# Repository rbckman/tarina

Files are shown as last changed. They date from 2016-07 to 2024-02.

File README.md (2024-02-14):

This project has been renamed to Gonzo Pi
==========================================

for the latest release go to [https://github.com/rbckman/gonzopi](https://github.com/rbckman/gonzopi)

Tarina Retake
=============
The Filmmaking Device

Let's introduce this thing with a thing it made, [a film on youtube](https://youtu.be/Yl2oAxMtDV0?si=lXOYTpkJi1YFuO2u) !

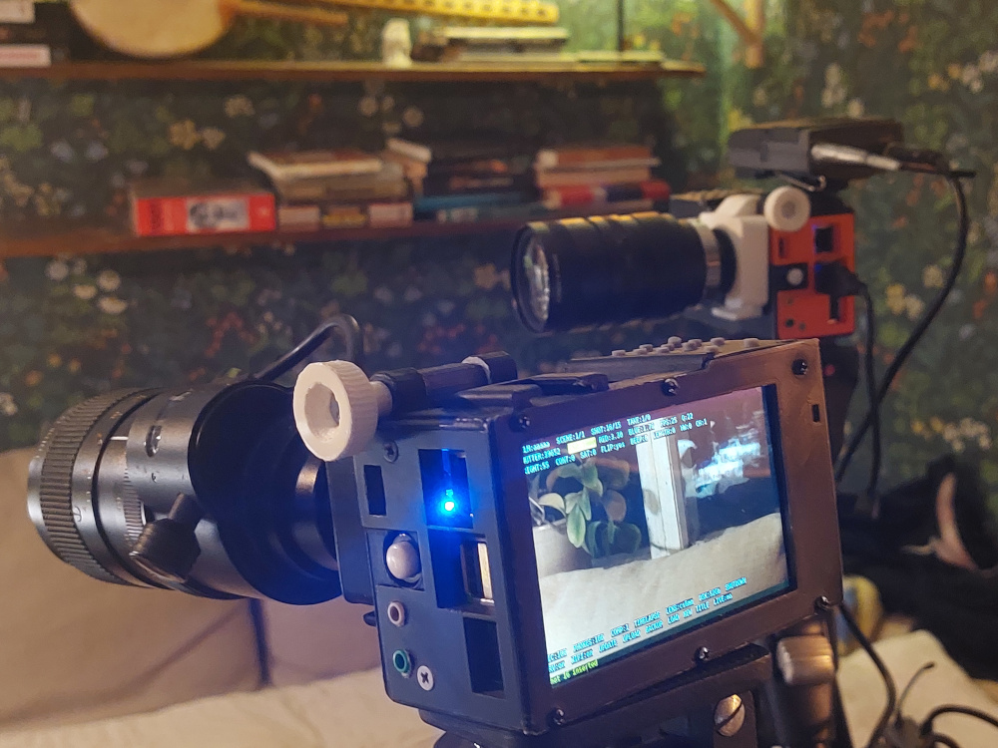
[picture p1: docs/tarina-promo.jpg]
Two buddies


Hollywood in your palms
--------------------------
Retake shots on the spot and see movie making magic in the filmmaking interface that runs Tarina Retake.
 
Software
--------
A video camera with *most of* the tools to make a film within the camera. That means alot of features. So far we have these key features running.
- glue the selected clips together and/or cutting them.
- making timelapses, voiceover, music track recording, slo-mo recording, fast-forward recording
- cut and copy and move clips around
- backup to usb harddrive or your own server
- upload or stream to youtube or your own server
- auto correction can easily be switched on or off for shutter, iso and colors so *operator* is in full control also for audio levels
- connect many Tarinas together for multicamera shooting
- stream a film a take or a scene through the network
- control the camera with silent physical buttons or a usb-wireless-keyboard or through https or ssh or ports, you choose.

It's all in there. But, where? in the filmmaking interface, that is Tarina Retake.

Hardware
--------
The parts have been chosen on the basis of features, quality, openness, availabilty and price. One of the key ideas of the project is to have a camera that could be upgraded or repaired by the fact that you easily just switch a component. The casis of the camera is 3d printable with a flipping gonzo style 180 shooting mode, please take a look [here to get the picture](https://github.com/rbckman/tarina/tree/master/3d)

### Buttons
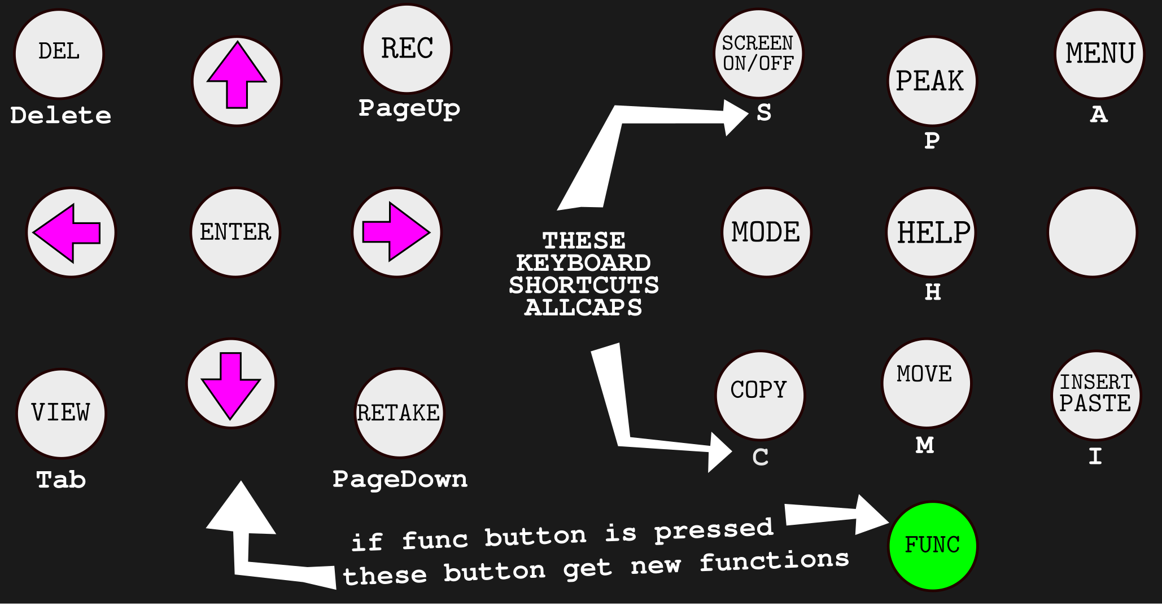
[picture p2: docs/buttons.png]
Buttons


Here's the main components: 

[Raspberry Pi 3 B](https://www.raspberrypi.org/products/raspberry-pi-3-model-b/)<br>
[Raspberry Pi High Quality Camera](https://www.raspberrypi.org/products/raspberry-pi-high-quality-camera/?resellerType=home) or <br>
[Pimoroni Hyperpixel 4 inch screen](https://learn.pimoroni.com/tutorial/sandyj/getting-started-with-hyperpixel-4)
[USB via vt1620a Sound card](https://www.aliexpress.com/item/Professional-External-USB-Sound-Card-Adapter-Virtual-7-1-Channel-3D-Audio-with-3-5mm-Headset/32588038556.html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)<br>
[3.7v 7800mAh li-ion Battery](https://www.aliexpress.com/item/3-7v-9000mAh-capacity-18650-Rechargeable-lithium-battery-pack-18650-jump-starter/32619902319.html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)<br>
[Type-C 5v 2A 3.7V Li-ion battery charger booster module](https://www.ebay.com/itm/Type-C-USB-5V-2A-3-7V-18650-Lithium-Li-ion-Battery-Charging-Board-Charger-Module/383717339632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)
[Buttons](http://www.ebay.com/itm/151723036469?_trksid=p2057872.m2749.l2649&ssPageName=STRK%3AMEBIDX%3AIT) connected to a [MCP23017-E/SP DIP-28 16 Bit I / O Expander I2C](http://www.ebay.com/sch/sis.html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)

Check [MANUAL](docs/tarina-manual.md) for complete part list & build instructions

[Ready to print 3d designs](https://github.com/rbckman/tarina/tree/master/3d)

Installing
----------
Download [Raspbian buster (not the latest!)](https://www.raspberrypi.org/downloads/raspbian/) and follow [install instructions | a simple install script should take care of it all!](https://www.raspberrypi.org/documentation/installation/installing-images/README.md).
[Ssh into](https://www.raspberrypi.org/documentation/remote-access/ssh/) Raspberry Pi and run:
```
sudo apt-get install git
```
Go to /home/pi/ folder
```
cd /home/pi
```
Git clone Tarina Retake and then run install script with sudo:
```
git clone https://github.com/rbckman/tarinaretake.git
cd tarinaretake
sudo ./install.sh
```
You'r ready to rumble:
```
python3 tarinaretake.py
```

Why
---
There are several reasons why.

- be able to repair if something breaks (this has been prooven as a very nice feature)
- be able to expand / build on it / make modifications
- be able to connect to it / program it to do things
- do a film on the fly without the need of another computer
- be able to watch your film directly on a screen once you're done filming
- learn about programming and your own crafts to really get down to the nitty-gritty. 

Connect
-------
Matrix [#tarina:matrix.tarina.org](https://riot.im/app/#/room/#tarina:matrix.tarina.org)

Mail rob(at)tarina.org

Standing on the shoulders of forward thinking, freedom loving generous people (powa to da people!)
--------------------------------------------------------------------------------------------------
This whole project has only been possible because of the people behind the free and open source movement. Couldn't possible list all of the projects on which shoulders this is standing for it would reach the moon. A big shout out to all of ya!! Yall awesome!

[Gnu](https://gnu.org), [Linux](https://github.com/torvalds/linux), [Debian](https://debian.org), [Raspberry Pi](https://raspberrypi.org), 
[Python programming language](https://python.org), Dave Jones's [Picamera python module](https://github.com/waveform80/picamera), rwb27 for lens shading correction! Check out the 3d printable microscope [Openflexure](https://github.com/rwb27/openflexure_microscope), [FFmpeg](https://ffmpeg.org/), [Libav-tools](https://libav.org/), [GPac library with MP4Box](https://gpac.wp.imt.fr/mp4box/), [Blender](http://blender.org), [aplay the awesome wav player/recorder with VU meter](http://alsa.opensrc.org/Aplay), [Popcornmix's Omxplayer](https://github.com/popcornmix/omxplayer), [Will Price's Python-omxplayer-wrapper](https://github.com/willprice/python-omxplayer-wrapper), [SoX - Sound eXchange](http://sox.sourceforge.net/), [The Dispmanx library](https://github.com/raspberrypi/userland/tree/master/host_applications/linux/apps/hello_pi), [Blessed](http://blessed.readthedocs.io/),  [web.py](http://webpy.org), [Tokland's youtube-upload](https://github.com/tokland/youtube-upload)

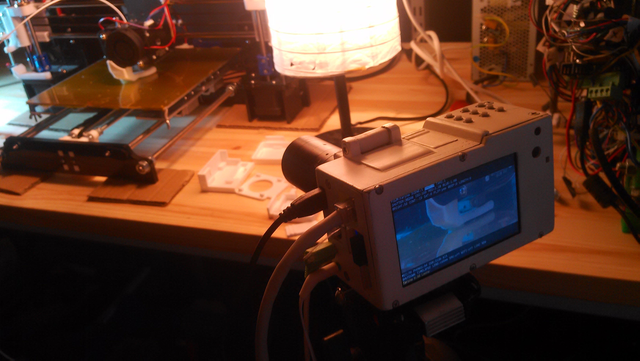
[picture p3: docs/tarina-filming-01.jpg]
Tarina and Leon


Some films made with Tarina
----------------------

### [Aakenustunturi Hiihtoretki 2023](https://youtu.be/VB7R2Eiw13k)

### [Mancherok](https://youtu.be/jmy0W6rA10Q)

### [Robins Trägård](https://youtu.be/IOZAHCIN6U0)

### [A new years medley](https://youtu.be/BYojmnD-1eU)

### [Landing Down Under](https://www.youtube.com/watch?v=Lbi9_f0KrKA)

### [Building Tarina](https://youtu.be/7dhCiDPssR4)

### [Mushroom Season](https://youtu.be/ggehzyUThZk)

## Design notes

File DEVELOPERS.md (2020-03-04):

DEVELOPERS
==========

If you want to join me in this journey to make the best open filmmaking camera please do not hesitate to contact me on features.

Teh best way to develop is using screen in terminal and starting tarina in one window then you'll get debug messages directly in that window.

THINGS
======

Notes to myself as I'm the only developer at teh moment.
-Rob

Quality / Usability
-------------------

Found a sweet spot between usability and quality (23), bitrate (5 mb/s)
This produces about 25 mb per minute. The convertion to mp4 format does not feel so slow anymore likewise the compiling of the film. This is good stuff.

Image sensors
-------------

There's plenty of image sensors for the Raspberry Pi to choose from, I want to support as many sensors I can. Currently though you need to change your sensor in tarina.py, search for 'ov5' and you'll find where to select. They all have different oscillators so the framerate varies pretty much. But when you get it right the sound will be in sync. Will make a tarina config file in home folder so when you start tarina interface for the first time it will ask you about your sensor.

Cancel renderer
---------------

This is a must feature, and I sort of know how to implement it.

Viewfinder for 3.5 inch screen
------------------------------

There's no such thing to buy so I had to make a viewfinder myself, took a while before I found the right convex lens but I have it now. It works with magnet snap on. Really, really usefull! will write it in the manual as a addon thing...

How to update alsa-tools arecord
=================================

The vumeter comes directly from alsa-tools arecord, it's just modified so it writes the vumeter directly to /dev/shm/vumeter. If you need to update alsa-tools here's how:

You need to be able to build alsa-utils from source
enable dev-src in /etc/apt/sources.list

```
apt source alsa-utils
cd alsa-utils*
sudo apt update
sudo apt install libncurses5-dev
sudo apt install libasound2-dev
./configure
make
cd aplay
make
make arecord
```

Ecasound update
===============

### Python example

```
from pyeca import *
e = ECA_CONTROL_INTERFACE()
e.command("cs-add chainsetup")
e.command("c-add 1st_chain")
e.command("ai-add plughw,0,0 ")
e.command("ao-add /dev/dsp")
e.command("cop-add -efl:100")
e.command("cop-select 1")
e.command("copp-select 1")
e.command("cs-connect")
e.command("start")
```

### Ecasound config file

```
# ecasound chainsetup file

# general 
-B:rtlowlatency -n:"write_chain" -X -z:noxruns -z:nopsr -z:mixmode,sum

# audio inputs 
-a:1chain,2chain -f:s16_le,2,44100 -i:alsahw,3,0,0

# audio outputs 
-a:1chain -f:s16_le,2,44100 -o:alsahw,3,0,0
-a:2chain -f:s16_le,2,44100 -o:test.wav,
```

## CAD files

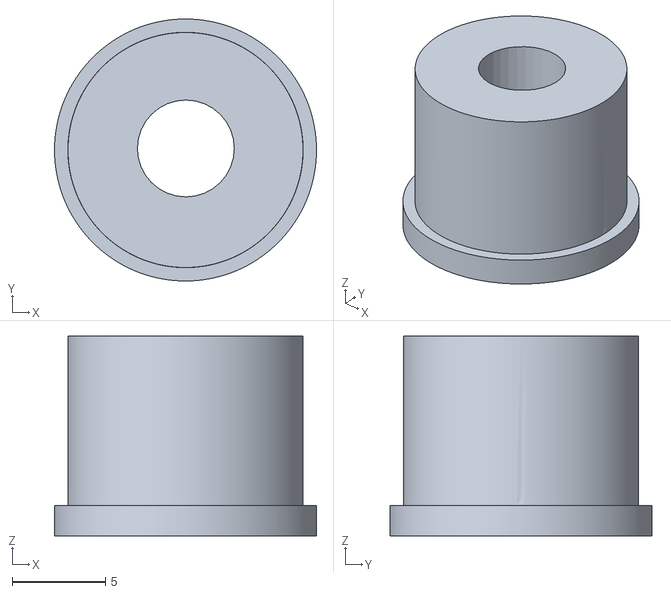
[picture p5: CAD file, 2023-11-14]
3d/tarina-picamera-clipgrip.stl
14.1 x 14.1 x 10.7

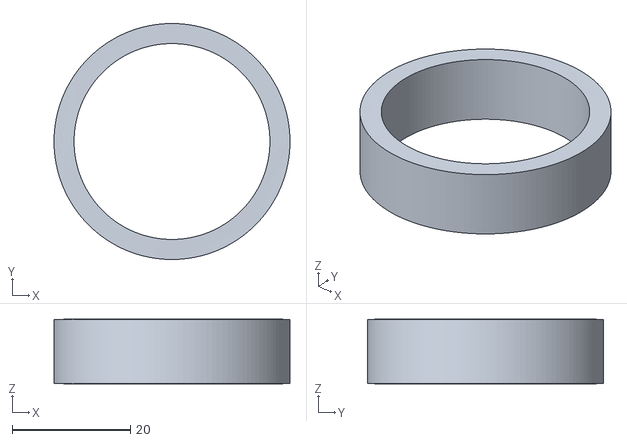
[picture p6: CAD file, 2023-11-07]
3d/tarinaloop.stl
40.0 x 40.0 x 11.0

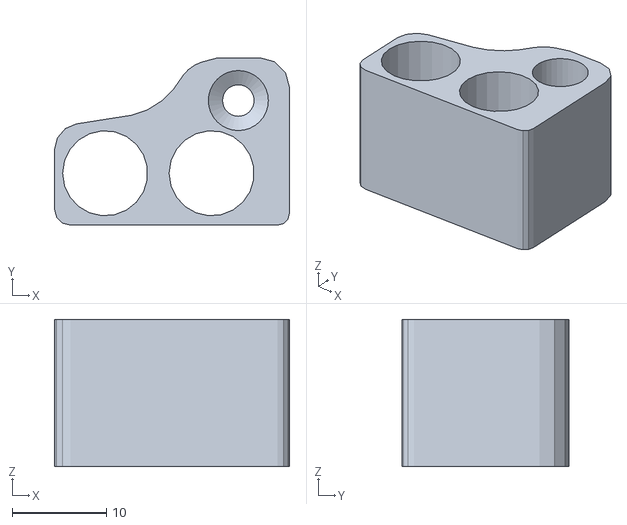
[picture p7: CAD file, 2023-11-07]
3d/miniplug-bend-stopper.stl
24.9 x 17.8 x 15.6

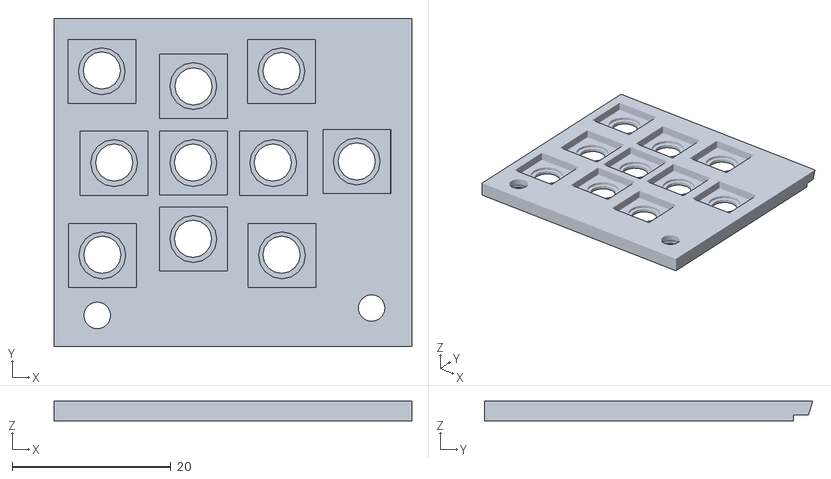
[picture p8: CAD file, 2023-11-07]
3d/tarina-button-plate-upper.stl
45.1 x 41.4 x 2.51

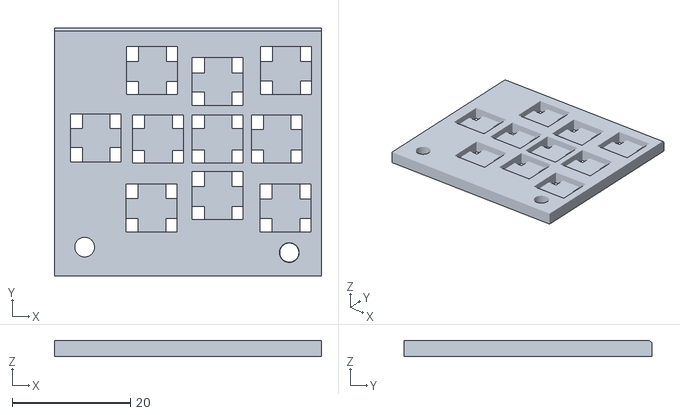
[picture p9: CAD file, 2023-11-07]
3d/tarina-button-plate-bottom.stl
45.1 x 41.9 x 2.71

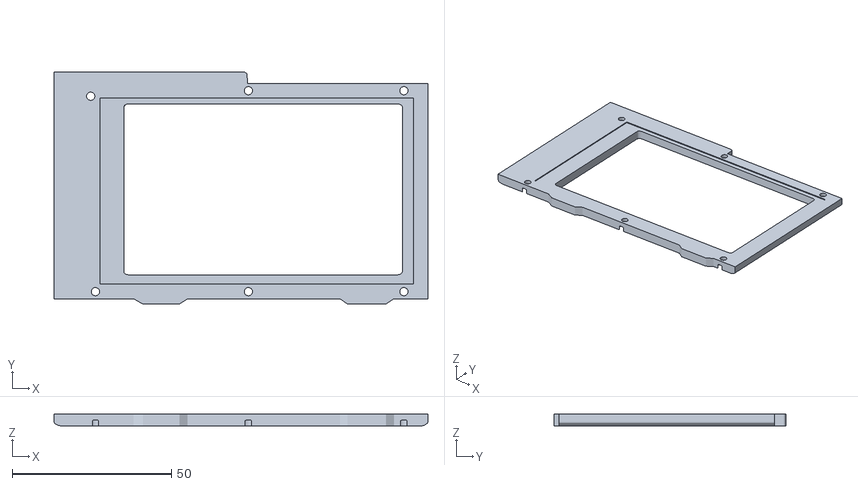
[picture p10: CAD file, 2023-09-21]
3d/tarina-screen-lid-hyperpixel.stl
117.4 x 72.8 x 3.68

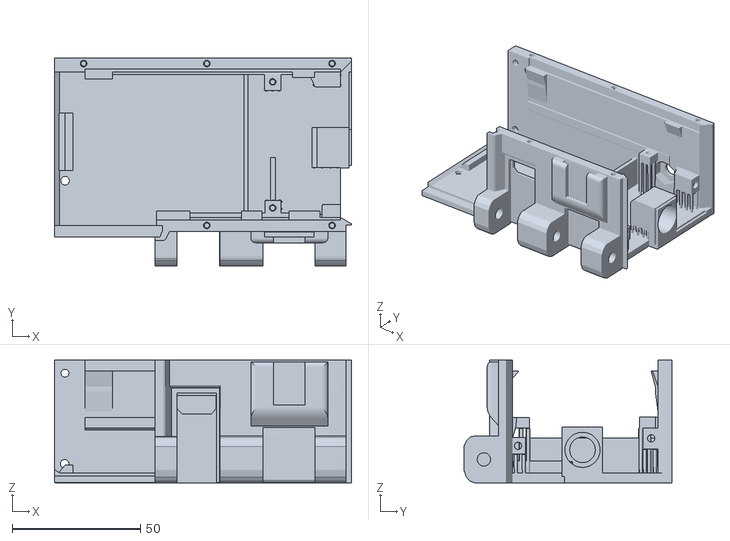
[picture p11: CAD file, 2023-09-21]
3d/tarina-body.stl
115.7 x 81.2 x 47.9

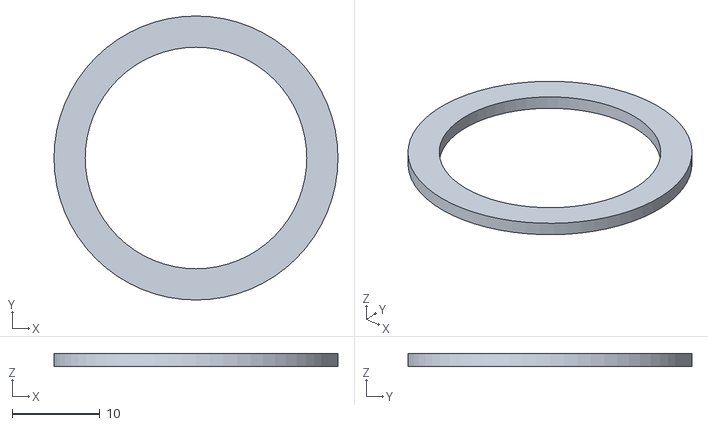
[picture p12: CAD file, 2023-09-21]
3d/cs-extension-tube.stl
32.4 x 32.4 x 1.50

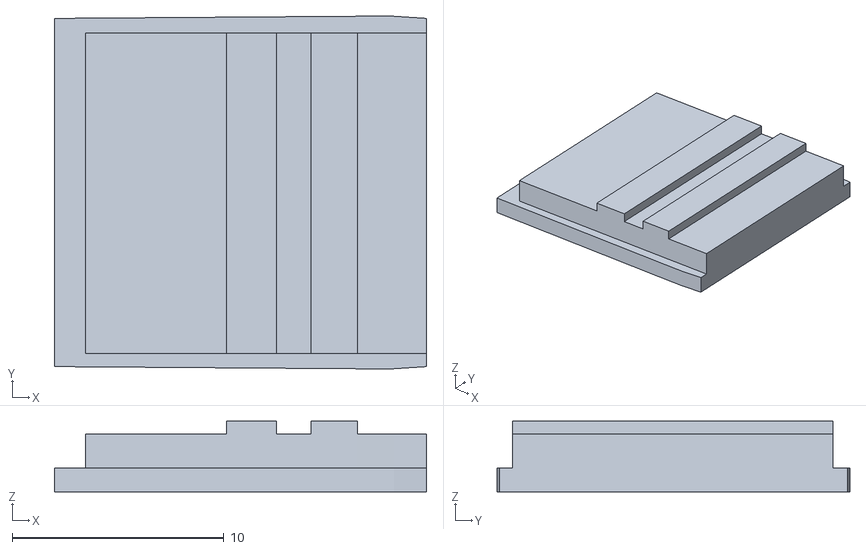
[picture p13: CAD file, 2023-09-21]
3d/tarina-hdmi-cap.stl
17.6 x 16.6 x 3.35

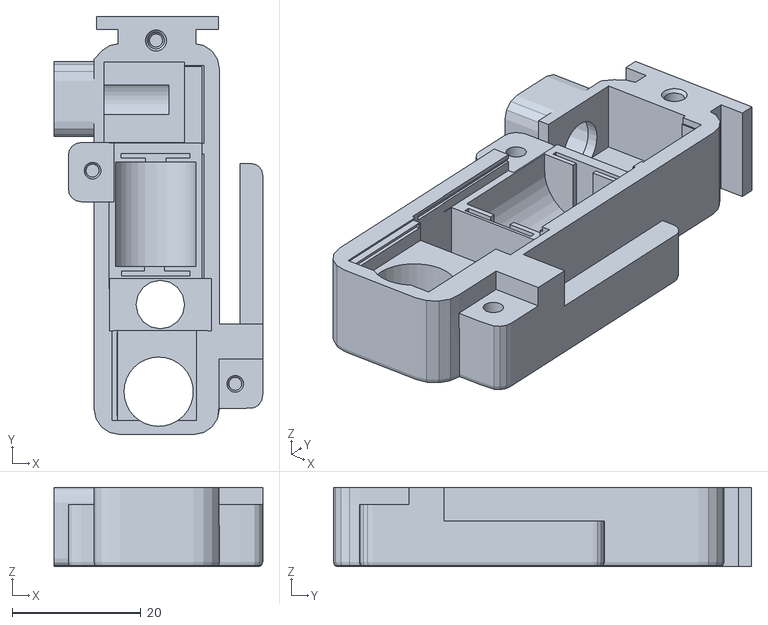
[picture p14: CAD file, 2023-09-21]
3d/tarina-mic-body.stl
32.3 x 64.8 x 12.3

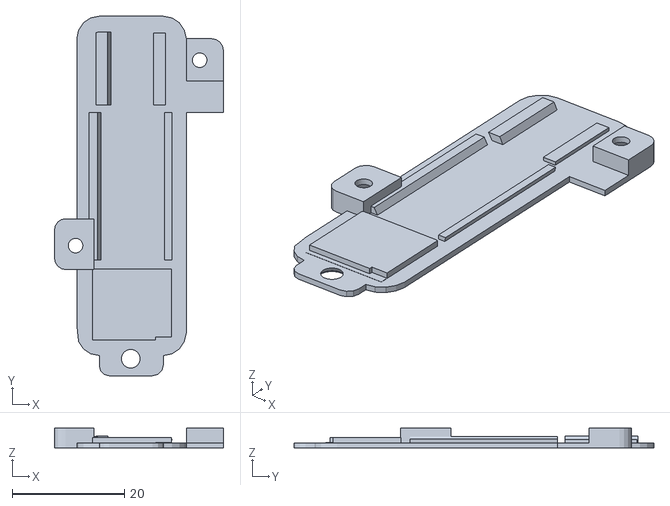
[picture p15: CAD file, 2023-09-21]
3d/tarina-mic-lid.stl
30.1 x 64.1 x 3.55

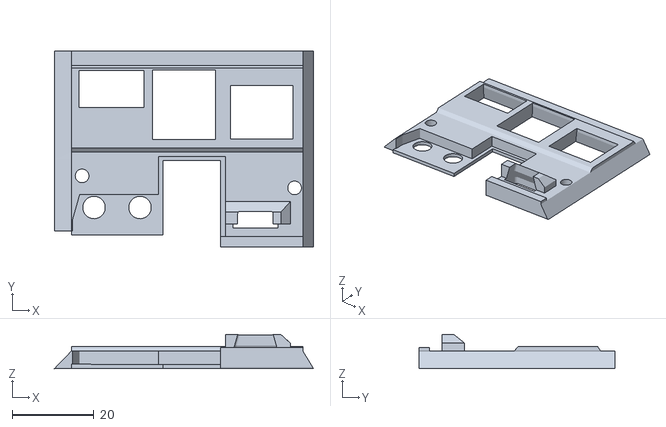
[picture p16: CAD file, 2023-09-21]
3d/tarina-left-side.stl
63.2 x 47.9 x 8.32

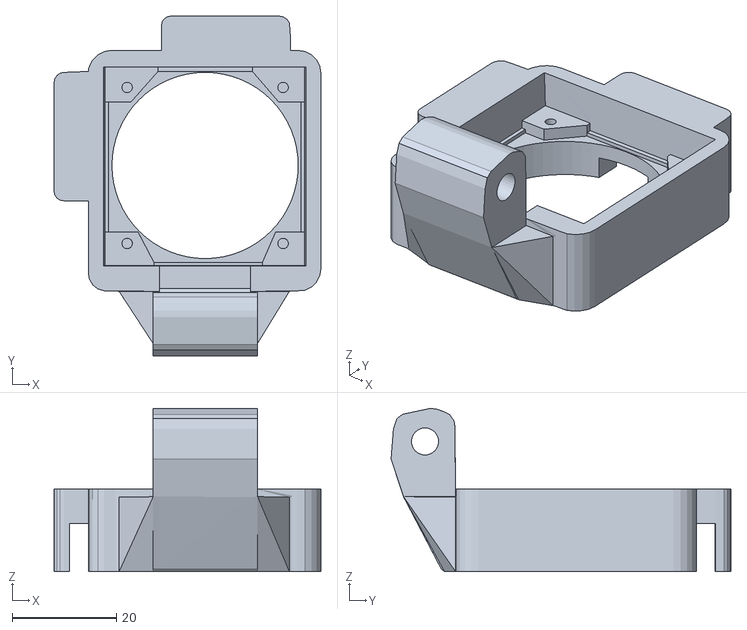
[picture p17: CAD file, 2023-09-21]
3d/tarina-picamera-hq-body.stl
51.3 x 65.3 x 31.4

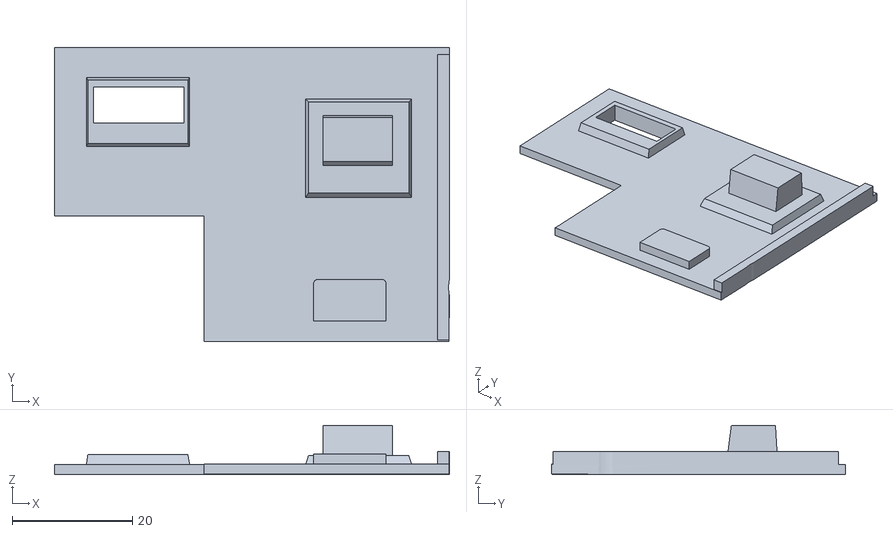
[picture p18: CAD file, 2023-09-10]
3d/tarina-left-side-cap.stl
65.7 x 48.9 x 8.18

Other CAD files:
3d/tarina-right-side.stl
3d/tarina-screen-lid-ugeek.stl
3d/tarina-picamera-hq-body-lid.stl
3d/viewfinder-clip-bridge3.stl
3d/button-symbols.stl
3d/tarina-modifyer-body-logo.stl
3d/tarina-modifyer-button-icons.stl
3d/tarina-picamera-body-lid.stl
3d/tarina-picamera-body.stl
3d/tarina-picamera-bridge.stl
3d/tarina-picamera-screwhandle.stl
3d/tarina-plate.stl
3d/tarina-screen-lid.stl
3d/tarina-viewfinder-eyepiece.stl
3d/tarina-viewfinder-hyperpixel.stl
3d/tarina-viewfinder.blend
3d/tarina-viewfinder.stl
3d/viewfinder-clip-bridge.stl
3d/viewfinder-clip-bridge2.stl

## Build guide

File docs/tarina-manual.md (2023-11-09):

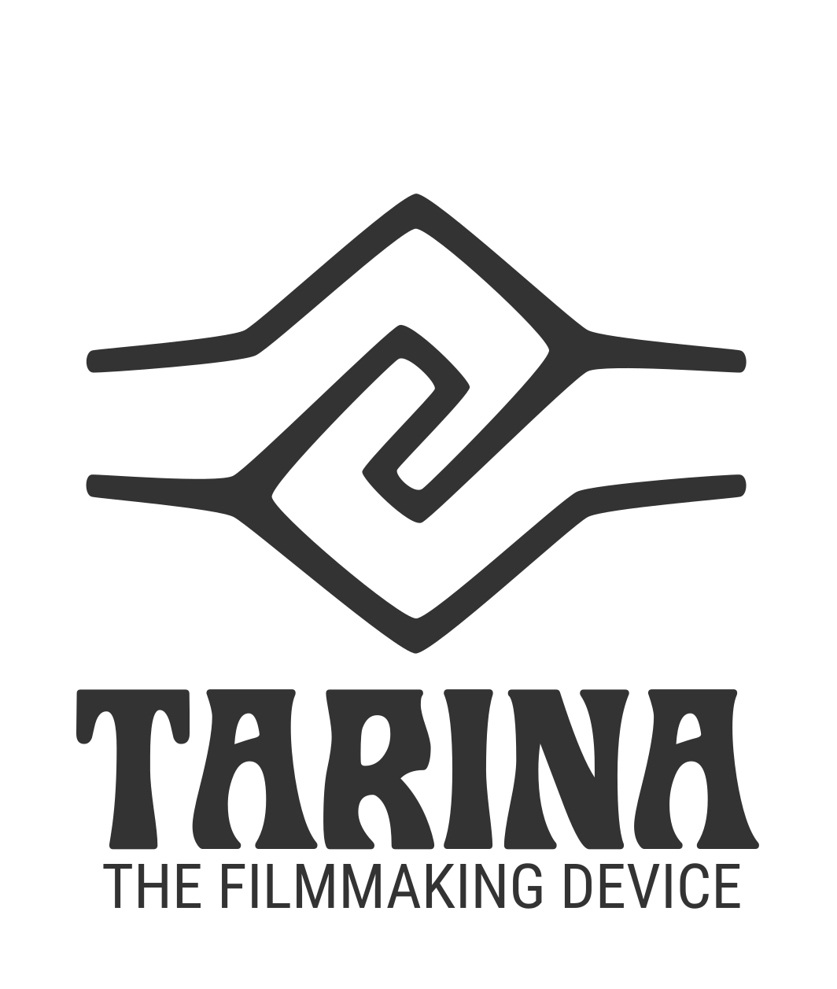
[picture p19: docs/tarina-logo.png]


<br>

MANUAL
======

Filming with Tarina

Contents
--------
### The interface
1. [Introduction](#introduction)
2. [Keys](#keys)
3. [Menus](#menus)
4. [Faq](#faq)

### [Building, repairing & modding]
1. [Get the parts](#get-the-parts)
2. [3d printing](#3d-printing)
3. [Post processing](#post-processing)
4. [Wiring](#wiring)
5. [Putting it together](#putting-it-together)
6. [Installing software](#installing-software)
7. [Tested lenses](#tested-lenses)

Introduction
============
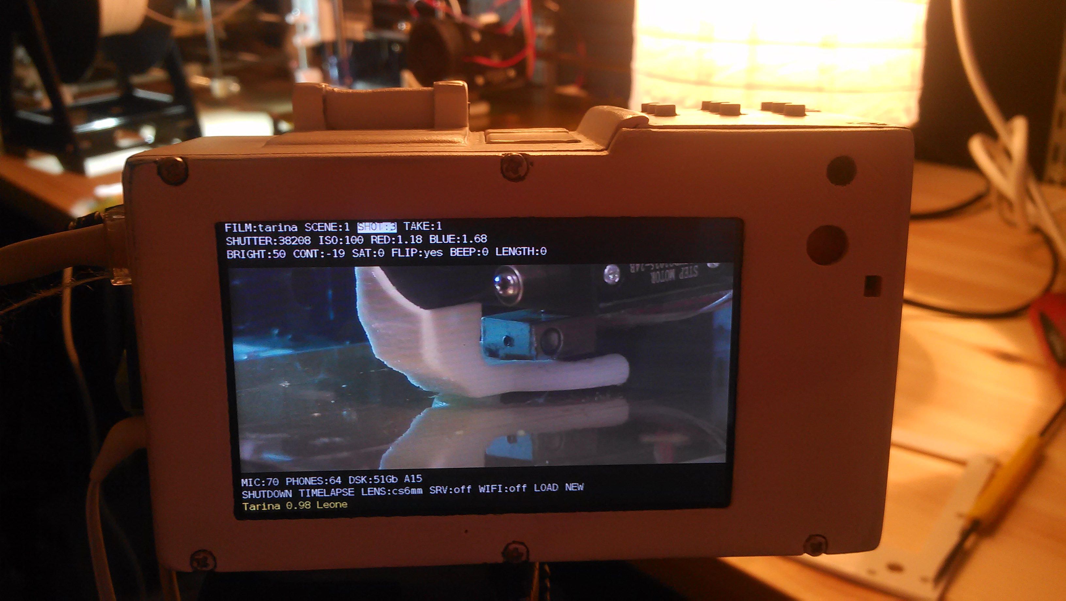
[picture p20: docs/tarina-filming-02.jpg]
Tarina UI


The interface presents all the essential tools in film making under one menu that is present and accessible all the time. You can control it with a keyboard or with the physical buttons; Enter, Up, Down, Left, Right, Record, Retake, View and Remove.

Retake function
---------------

Always after recording a take you'll be presented with the last frame of that take. Now, if you are happy with it, press record again and you'll move to the next shot in your movie, oterwise press retake and you'll be filming a new take of that shot. At the time of writing the last take is always chosen into your movie film.

Hint! pressing record while browsing existing takes, shots and scenes will take you to the last shot in that scene. Pressing retake will do just that, a retake. Makes perfectly sense, right? Fiddle around with it, you'll totally get it.

Keys
====

### Buttons
Buttons

### Keyboard
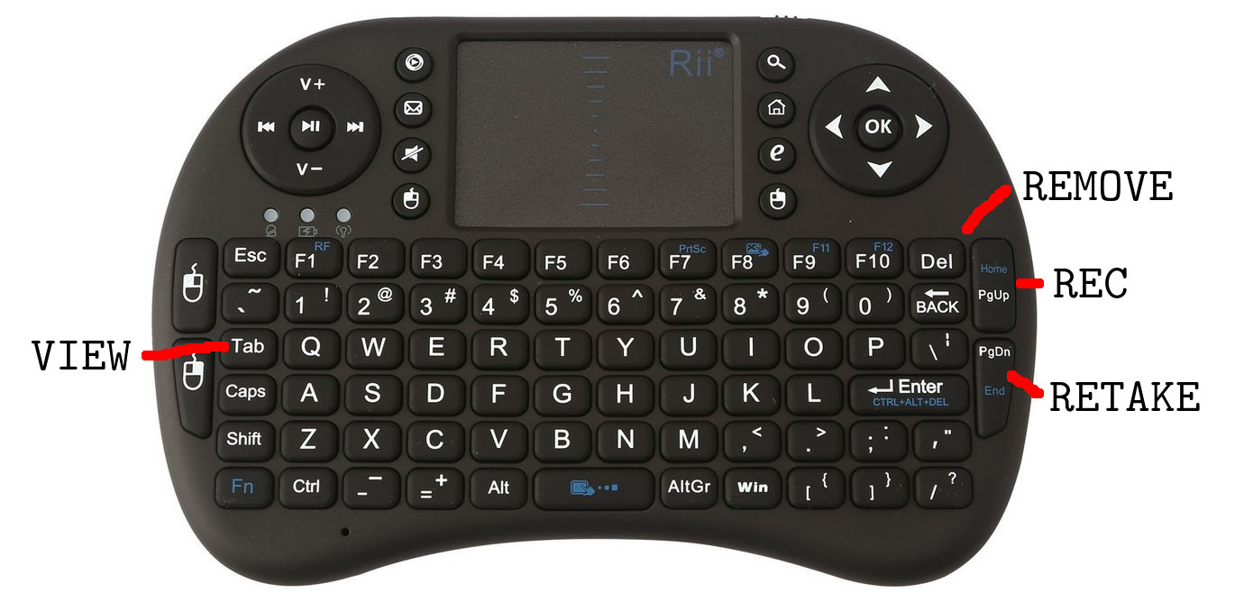
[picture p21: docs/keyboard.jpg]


With keys up and down you change a specific setting, for example shutter speed. With keys left and right you change what settings to change. With view, you can view the last shot or if you have a specific scene highlighted the camera would automatically glue all shots together and play that scene for you, same goes for film. With remove you can remove a specific take, shot, scene or film. With the retake button you retake a bad take, this is how the camera keeps track of your good takes. The last take is always the chosen one.

Special keys on the keyboard (CAPITAL):

C = Copy scene/shot

M = Cut (as in cut and paste) scene/shot

I = Insert empty or copied scene/shot

space / pgup = Rec / Stop

pgdwn / backspace = Retake

tab = view

Menus
=====
A short explanation of all the settings and why they are where they are.

### Film, scene, shot and take
This you don't see on other cameras because they don't care about what you're filming, however this camera does and it wants to know where you are in your filmmaking process and help put it together. Of course, this means that ***you*** have to know where you are in your filmmaking process. The idea of the workflow is: film only the essentials, check your montage on the spot and do a retake if you need to fix something rather than filming a bunch of things and fixing it later on. This will save ***you*** alot of time.

### Dubbing
If you press enter while you've highlighted the film name or a scene you'll be entering dub settings menu. (ADD:d:1.0/o:1.0) this indicates the volume of the (d)ub to the previous (o)riginal mix. So, for example if you want the dub volume to be 50% of the previous audio, the settings would look like this (ADD:d:0.5/o:1.0). A good all-around background music volume level is only 10% so it would look like this (ADD:d:0.1/o:1.0). The other setting is fade in and out in seconds (in: 0.5) (out: 1.0) whould be half a second in and a second out. Now if you press enter while the ADD is highlighted you'll be dubbing. You can change the settings later if you come back to the menu.

### Shutter, iso, red, blue
Shutter and iso are well know basic camera concepts. With red and blue you control the colors. If you press enter while on any of these then it will go into auto mode and if you press it again it will go back to manual mode with the current auto settings. I'm using this feature to quickly find a reasonable good value before I'm locking and tuning the settings manually to my likings. Cuz you always will know better than the robots!

### Bright, cont, sat
Color grade on the go with brightness, contrast and saturation. You will probably have to play with theses to figure out what you want. Remember that as you're making your film ready while you're shooting it take by take, there's no color grading later on so you'll have to settle on your color grade before you film. To get that good old spaghetti western look go with the contrast at -19.

### Flip, beep, lenght
If you go gonzo, flippin it is the way to go! beep is a countdown timer from the moment you press rec or retake to when it actually starts filming. Lenght let's you put in the lenght of your take before you actually start filming. Both of these are very useful if you film action alone and can't reach for the buttons. 

### Mic, phones, comp
Control teh level of your mic and headphones. Comp is a basic compressor so your message comes across and we hear ya! it's quite harsh at the moment but I like it when it goes craking up abit like in the good old 70s cinema.

### Timelapse
Do a timelapse when you need to tell about time. There's an under menu here where you can choose the intervall of the takes, now this isn't really a traditional timelapse, it will instead do a 0.2 sec video at each intervall or it can be set to your likings but 0.2 is good for a traditional timelapse effect. At the bottom of the screen is a calculation of how long the clip will be if you do the timelapse for an hour. I'd say don't over do it! a 10 - 20 sec clip is already quite a stretch but its up to you, you're the movie film director.

### Lens
A future implementation of lens shade correction will come where you get to do your own lens corrections to get those colors right on the spot!

### Dsk, shutdown, srv, wifi
Disk space, showing you how much of space left on your sd card. Shutdown, when your really done! it's good to do this before cutting the power or otherwise there's a small chance of sd card corruption. Srv is a network server, if your connected to a network and put this on you should be able to go to any browser on any device and watch your movie films (that is if you've rendered them first), just go to http://tarina.local or it might be that you have to know the ip address of your tarina (you'll find it when you've connected it. Press enter on wifi. There it is on the bottom of the screen, looks like this 192.168.1.105). If you press enter on wifi you will be transported to a glorious program called Wicd curses, here you really need to have a keyboard to set up your connections. Hints are down on the screen what buttons to press. To get back into Tarina press "q".

### Update and upload
Update the camera to the most exclusive version, this is still pretty much a-work-in-progress and as a warnign expect some bugs! don't worry I'll be improving things but it takes time. Upload your film to the web, there is a youtube uploader mod you can install but you'll have to do some configs to make it work for you. Details coming soon. Reach out to the matrix room if you're in a hurry..

to get the youtube api secrets `wget https://tarina.org/yt/.client_secrets.json`

### Backup
It's good to always backup your stuff! Plug in your usb drive and just press enter and sit back and relax as the wonderful work of computer copying does the magic. While you're at it open a beer cuz it can take quite a while if you got much stuff on there. Now, this should be working on almost all hard drives but there are some that still use a very old file system called fat, and its as lazy as its given name and doesnt store critical information we would want, because we want the copying to only copy our new takes or retakes. So please use new drives like ntfs systems or ext or whatever they all are called. You'll find all your takes even the shitty ones on your harddrive in a directory called /tarinafilms/. One more thing, there are some drives that are very power hungry and doesnt come with it's own power source, now these drives are very bad for this particular use because the Tarina has limited amounts of power for usb use, so to be sure it's gonna work, use powered hard drives that has got a power cord.

### Load and new
You can have many on going films, load em up or start as many films as you like.

------------------------------

Building, repairing and modding
===============================

Get the parts
--------------

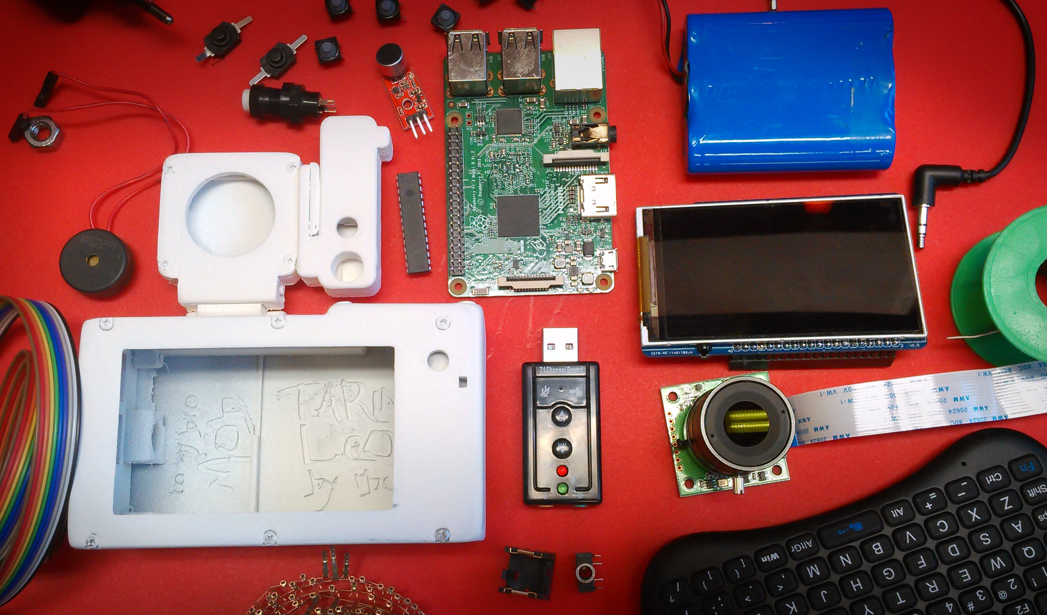
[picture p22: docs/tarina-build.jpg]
Tarina parts layed out


Here is a list of parts that will work, there are other parts that probably will work but requires some hacking.

Raspberry pi 3 B
----------------
Price ~30 eur

The heart of Tarina. Why Raspberry pi you ask? There are several reasons:

* Huge support.
* The great Debian based os Raspbian (beeing a debian nerd myself).
* Low price.
* Picamera.

The 3B+ is too powerhungry for the Powerbooster 1000C thats why I went with 3B

**Links**
[Raspberry pi site](https://raspberrypi.org)
**Buy**
[Aliexpress](https://www.aliexpress.com/store/product/Raspberry-Pi-3-Model-B-Raspberry-Pi-Raspberry-Pi3-B-Pi-3-Pi-3B-With-WiFi/3242037_32900816535.html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,searchweb201602_5_10065_10068_5016020_5015416_10059_10696_100031_5015320_10084_10083_10103_451_10618_452_5016116_10304_10307_10820_10821_10302,searchweb201603_55,ppcSwitch_2&algo_expid=0a48bb10-5985-49ff-be76-433eb1f8685b-15&algo_pvid=0a48bb10-5985-49ff-be76-433eb1f8685b&priceBeautifyAB=0)

64 Gb Samsung Evo+ Micro SD
---------------------
Price ~10 eur

This is a good performance card.

[Aliexpress](https://www.aliexpress.com/item/32676225311.html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,searchweb201602_7,searchweb201603_55)

Raspberry Pi High Quality Camera (recommended)
----------------------------------------------
Price ~60 eur

This is the recommended camera module for Tarina, 12.3 megapixel Sony IMX477 sensor, 7.9mm diagonal image size, and back-illuminated sensor architecture, with adjustable back focus and support for C- and CS-mount lenses.

**Links**
**Buy**
[Raspberry pi](https://www.raspberrypi.org/products/raspberry-pi-high-quality-camera/?resellerType=home)

Arducam 5 MP OV5647 camera module with CS lens
----------------------------------------------
Price ~30 eur

This module and lens gives good hd video quality with the ability to manually focus and replace lenses. See tested lenses down below.

**Links**
[Arducam](http://arducam.com/)
**Buy**
[ebay](https://www.ebay.com/itm/OV5647-Camera-Board-w-CS-mount-Lens-for-Raspberry-Pi-3-B-B-2-Model-B-/281212355128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)

Pimoroni Hyperpixel 4 inch screen
-----------------------------
Price ~35 eur

Bright 4 inch responsible screen. Beware when installing the screen, it's quite britle!

**Links**
[Pimoroni](https://learn.pimoroni.com/tutorial/sandyj/getting-started-with-hyperpixel-4)
**Buy**
[Pimoroni](https://shop.pimoroni.com/products/hyperpixel-4)
[Farnell](https://fi.farnell.com/pimoroni/pim370/hyperpixel-board-raspberry-pi/dp/3401805)

Ugeek 3.5 inch 800x480 TFT screen
---------------------------------
Price ~35 eur

Best 3.5 inch screen that I could find. Features worth mentioning:

* 800x480 pixels
* Very responsible 11 ms.
* High contrast.
* Sunlight readable. (even though it is readable in full power mode, it boots into medium power and to change it yo to push a physical button which isnt really dooable cuz of tha casing. you cant easily change the settings, I am abandoning this screen due to this)
* I2C Master.

This is not a touchscreen but I dont think touchscreens are good for cameras anyway. 

**Links**
[Raspberrypiwiki](http://www.raspberrypiwiki.com/index.php/3.5_inch_TFT_800x480@60fps)
**Buy**
[Aliexpress](https://www.aliexpress.com/store/product/U-Geek-Raspberry-Pi-3-5-inch-800-480-TFT-Screen-HD-HighSpeed-LCD-Module-3/1954241_32672157641.html)

USB via vt1620a sound card
--------------------------
Price ~1 eur

Really cheap usb soundcard. It has been working suprisingly well. Have not tested other cards yet.

**Buy**
[Aliexpress](https://www.aliexpress.com/item/Professional-External-USB-Sound-Card-Adapter-Virtual-7-1-Channel-3D-Audio-with-3-5mm-Headset/32588038556.html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)

3.7v 7800mAh li-ion Battery
---------------------------
Price ~17 eur

I have tried several batteries, the adafruit 6800mAh is also fine.

**Buy**
[Aliexpress](https://www.aliexpress.com/item/free-shipping-3-7v-7800mah-18650-li-ion-rechargeable-battery-pack-18650-3P-lithium-ion-battery/32823635264.html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)

Or you can buy 3 pcs of 3.7V 18650 Lithium cells and protect them with an Lithium Battery Protection Board Overcharge Over-discharge.

[Aliexpress](https://www.aliexpress.com/item/32826851071.html?spm=a2g0s.9042311.0.0.27424c4dUBojcv)

Here's a pack with 40 pcs of 2600mAh 3.7V 18650 cells.

[Aliexpress](https://www.aliexpress.com/item/32795814865.html?spm=a2g0s.9042311.0.0.27424c4dUBojcv)

Type-C 5v 2A 3.7V Li-ion battery charger booster module
-------------------------------------------------------
Price ~2€

Enough juice in this booster charger to run teh pi 3b without dropping voltage.

**Buy**
[Ebay](https://www.ebay.com/itm/Type-C-USB-5V-2A-3-7V-18650-Lithium-Li-ion-Battery-Charging-Board-Charger-Module/383717339632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)

Adafruit Powerboost 1000C
-------------------------
Price ~23 eur

Seems to be dropping voltage every now and then resulting in dropped frames. Check the Type-C power booster.

**Links**
[Adafruit](https://www.adafruit.com/product/2465)
**Buy**
[Ebay](https://www.ebay.com/itm/Adafruit-PowerBoost-1000-Charger-Rechargeable-5V-Lipo-USB-Boost-1A-1000C-A/282083284436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)
[Aliexpress](https://www.aliexpress.com/item/32881790567.html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,searchweb201602_7,searchweb201603_55)

8x8x5MM DIP-4 Silicone Switch Mute Silent button
------------------------------------------------
Price ~2 eur/20 pcs

You can only buy a pack of 20 pcs but these buttons are good and silent! Not necessary if you want to control with keyboard like Rii mini 8+

**Buy**
[Ebay](http://www.ebay.com/itm/151723036469?_trksid=p2057872.m2749.l2649&ssPageName=STRK%3AMEBIDX%3AIT)
[Aliexpress](https://www.aliexpress.com/item/32777086031.html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,searchweb201602_7,searchweb201603_55)

MCP23017-E/SP DIP-28 16 bit I / O expander I2C
-----------------------------------------------
Price ~1 eur

This will be connected to the screen I2C port. This is not necessary if you intend to control the camera with a keyboard like the Rii mini i8+

**Buy**
[Aliexpress](https://www.aliexpress.com/item/10PCS-MCP23017-E-SP-DIP-28-MCP23017-16-Bit-I-O-Expander-with-I2C-Interface-IC/32665631086.html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)

2x8cm double side copper prototype pcb
--------------------------------------
Price ~0.20 eur/pcs

PCB board to solder all connections on the MCP23017-E/SP

**Buy**
[Aliexpress](https://www.aliexpress.com/item/5pcs-2x8cm-double-Side-Copper-prototype-pcb-2-8-panel-Universal-Board-for-Arduino-Free-Shipping/32820588012.html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)

Piezo electronic buzzer
-----------------------
Price ~1 eur

Very useful for timing shots!

**Buy**
[Aliexpress](https://www.aliexpress.com/store/product/New-Arrival-Durable-3-24V-Piezo-Electronic-Buzzer-Alarm-95DB-Continuous-Sound-Beeper-For-Arduino-Car/1959068_32666789405.htm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,searchweb201602_3_10065_10068_10059_5015413_5015313_10696_100031_10084_10083_5016113_10103_451_10618_452_10304_10307_10820_10821_10302_5016013,searchweb201603_45,ppcSwitch_4_ppcChannel&algo_expid=c84318cd-b50e-4370-9cad-6ae9bc7963ae-0&algo_pvid=c84318cd-b50e-4370-9cad-6ae9bc7963ae&priceBeautifyAB=0)

Latching push button switch mini
---------------------------------
Price ~1 eur/10 pcs

This serves as the microphone and screen on/off button

**Buy**
[Aliexpress](https://www.aliexpress.com/item/10Pcs-Set-1A-30V-DC-250V-Black-Latching-On-Off-Mini-Torch-Push-Button-Switch-G08/32756874522.html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)

Latching push button switch 10mm
--------------------------------
Price ~5 eur/24 pcs

I use this as the powerbutton. I have tried different versions of safe shutdown buttons for the Raspberry pi but they have not worked as I wanted (they draw power even when Pi is powered off, this is not good). I have solved the problem with a menu button to safely shut down the camera. 

**Buy**
[Aliexpress](https://www.aliexpress.com/item/24pcs-latching-push-button-switch-10mm-fixed-pushbutton-switch-latching-maintained-push-buttons/32770346793.html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)

Nut 1/4 -20 UNC 304 A2 
-----------------------
Price ~2 eur/10 pcs

This is the standard camera stand nuts. If you never use a stand then you dont need this.

**Buy**
[Ebay](https://www.ebay.com/itm/1-4-20-UNC-304-A2-Stainless-Steel-Hex-Full-Nuts-Qty-10PCS-/222134363896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)<br>

MAX9812 Microphone amplifier
----------------------------
Price ~2 eur

This makes suprisingly good sounding sound! The original piece that I used is out of production, I have now found a similar module but I need to change the 3d module a little bit because the new module is alot smaller which is good. Need to test these new ones!

**Buy**
[Aliexpress](https://www.aliexpress.com/item/32793366801.html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,searchweb201602_7,searchweb201603_55) (out of stock)
[Ebay](https://www.ebay.com/itm/MAX9812-Microphone-Amplifier-Sound-MIC-Voice-Module-For-Arduino-3-3V-3-5V/123891576683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) (out of stock)

New module (still untested) [Aliexpress](https://www.aliexpress.com/item/33052676199.html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,searchweb201602_,searchweb201603_)
Bigger electrec mics (if needed) [Aliexpress](https://www.aliexpress.com/item/32639718325.html?spm=a2g0s.9042311.0.0.27424c4d7cO7CI) 

3.5mm Female stereo headset interior PCB mount
----------------------------------------------
Price ~1 eur/10 pcs

Microphone input.

**Buy**
[Ebay](https://www.ebay.com/itm/10pcs-3-5mm-Female-5-Pins-Stereo-Headset-Interior-PCB-Mount-Audio-Jack-Socket-/252376936189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)

LR44 Batteries
--------------
Price ~2 eur/10 pcs

Microphone batteries

**Buy**
[Aliexpress](https://www.aliexpress.com/store/product/10PCS-Lot-100-Genuine-wholesale-GP-A76-GPA76-LR44-AG13-LR44-SR44-battery-LR44-357-AG13/1120058_32739450265.html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,searchweb201602_5_10065_10068_5015418_5016020_10059_10696_100031_5015320_10084_10083_10103_451_10618_452_10304_10307_10820_10821_5016118_10302,searchweb201603_55,ppcSwitch_2&algo_expid=8af0bcbe-dcb8-4f9a-bd47-084a4d77561a-6&algo_pvid=8af0bcbe-dcb8-4f9a-bd47-084a4d77561a&priceBeautifyAB=0)

Screws M3x12mm
-----------
Price ~2 eur/25 pcs

These hold the camera together.

**Buy**
Your local harware store

[Ebay](https://www.ebay.com/itm/50X-Stainless-M1-6-M2-M3-M4-Countersunk-Flat-Head-Cross-Miniature-Screw-Bolts/392195849737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)

Screws M3x30mm
---------------
Price ~2 eur/30 pcs

These hold picamera-body to the body.

**Buy**
[Ebay](https://www.ebay.com/itm/20-pcs-M3-Screw-Diameter-3mm-Length-30mm-M3x30-Stainless-Steel-DIY/181846978737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)

Screws 2.2x9.5mm
----------------
Price ~1 eur/20 pcs

These hold the camera/mic together.

**Buy**
[Ebay](https://www.ebay.com/itm/M2-2x9-5mm-Stainless-Steel-Phillips-Round-Pan-Head-Self-Tapping-Screws-50pcs/391417337610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)

LR44 Button cell socket holder
--------------------------------------
Price ~1 eur/pcs

We only need the metal parts from these, if you have som thin metal you could cut these yourself.

**Buy**
[Aliexpress](https://www.aliexpress.com/item/4-Pcs-Black-Plastic-Button-Coin-Cell-Battery-Socket-Holder-for-2-x-AG13-LR44/33013344736.html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)

3.5mm Jack to jack aux cable
----------------------------
Price ~1 eur

From microphone to mic-in.

**Buy**
[Aliexpress](https://www.aliexpress.com/store/product/1-Piece-Short-0-2M-20cm-Red-3-5mm-Jack-to-Jack-Aux-Cable-Male-to/505072_32833465555.html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,searchweb201602_5_10065_10068_5016020_10059_10696_100031_5015320_5016120_10084_10083_5015420_10103_451_10618_452_10304_10307_10820_10821_10302,searchweb201603_55,ppcSwitch_2&algo_expid=9ba0b376-e66f-48d2-9ccd-ecc1e8794812-1&algo_pvid=9ba0b376-e66f-48d2-9ccd-ecc1e8794812&priceBeautifyAB=0) 

Rii mini i8+ mini keyboard
--------------------------
Price ~17 eur

Wireless control over camera. You will also need this for wifi settings etc. (Recommended) This is one of the best mini keyboards I've tried. 

**Buy**
[Aliexpress](https://www.aliexpress.com/item/Rii-mini-i8-Russian-English-Spanish-Hebrew-Version-Wireless-Backlit-Keyboard-with-Touchpad-for-PC-Smart/32450468690.html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)

Parts grand total ~200 eur

Optional parts
==============

Tarina viewfinder 
-----------------

This is a 3.5 inch viewfinder for Tarina that you can 3d print and make by buying these three parts.

Lens D42 F110mm
---------------
Price ~10 eur

**Buy**
[Aliexpress](https://www.aliexpress.com/item/32958816619.html?spm=a2g0s.9042311.0.0.6fb54c4dGb4wI7)

Rubber Eyepiece
---------------
Price ~4 eur

**Buy**
[Aliexpress](https://www.aliexpress.com/item/32780859922.html?spm=a2g0s.9042311.0.0.27424c4dmVqriG)

Magnets 25mm x 5mm x 1.5mm
--------------------------
Price ~3 eur 10 pcs

**Buy**
[Aliexpress](https://www.aliexpress.com/item/32963277127.html?spm=a2g0s.9042311.0.0.27424c4dRc1vCZ)

3d printing
===========

While waiting for ordered parts lets 3d print the rest of the parts. I recommend printing with a solid 90% infill. Now it is pretty crucial that you have a good calibrated printer so that you don't over/under print. Some parts need to be very precise to work.

You'll find all the 3d parts in the 3d folder.

* [body](https://github.com/rbckman/tarina/blob/master/3d/tarina-body.stl)
* [button-plate-bottom](https://github.com/rbckman/tarina/blob/master/3d/tarina-button-plate-bottom.stl)
* [button-plate-upper](https://github.com/rbckman/tarina/blob/master/3d/tarina-button-plate-upper.stl)
* [hdmi-cap](https://github.com/rbckman/tarina/blob/master/3d/tarina-hdmi-cap.stl)
* [left-side](https://github.com/rbckman/tarina/blob/master/3d/tarina-left-side.stl)
* [mic-body](https://github.com/rbckman/tarina/blob/master/3d/tarina-mic-body.stl)
* [mic-lid](https://github.com/rbckman/tarina/blob/master/3d/tarina-mic-lid.stl)
* [picamera-body](https://github.com/rbckman/tarina/blob/master/3d/tarina-picamera-body.stl)
* [picamera-body-lid](https://github.com/rbckman/tarina/blob/master/3d/tarina-picamera-body-lid.stl)
* [picamera-bridge](https://github.com/rbckman/tarina/blob/master/3d/tarina-picamera-bridge.stl)
* [right-side](https://github.com/rbckman/tarina/blob/master/3d/tarina-right-side.stl)
* [screen-lid](https://github.com/rbckman/tarina/blob/master/3d/tarina-screen-lid.stl)

Post processing
===============

This is still a work in progress...

So far I've come to this conclusion:

* Put 3d printed parts together with screws.
* Sand with sandpaper from rough to finest (from 120 to 400). I like to sand down all corners making them round.
* Dust off.
* Paint.
* Wait til dry.
* Paint again.
* Wait til dry. I like to wait for atleast a day to make it really dry.
* Sand again.
* Paint and wait again.
* Continue like this til you are satisfied with the feel, now I like to have a good grip so I finnish with sanding with 400 grit paper and leave it like that.

Wiring
======

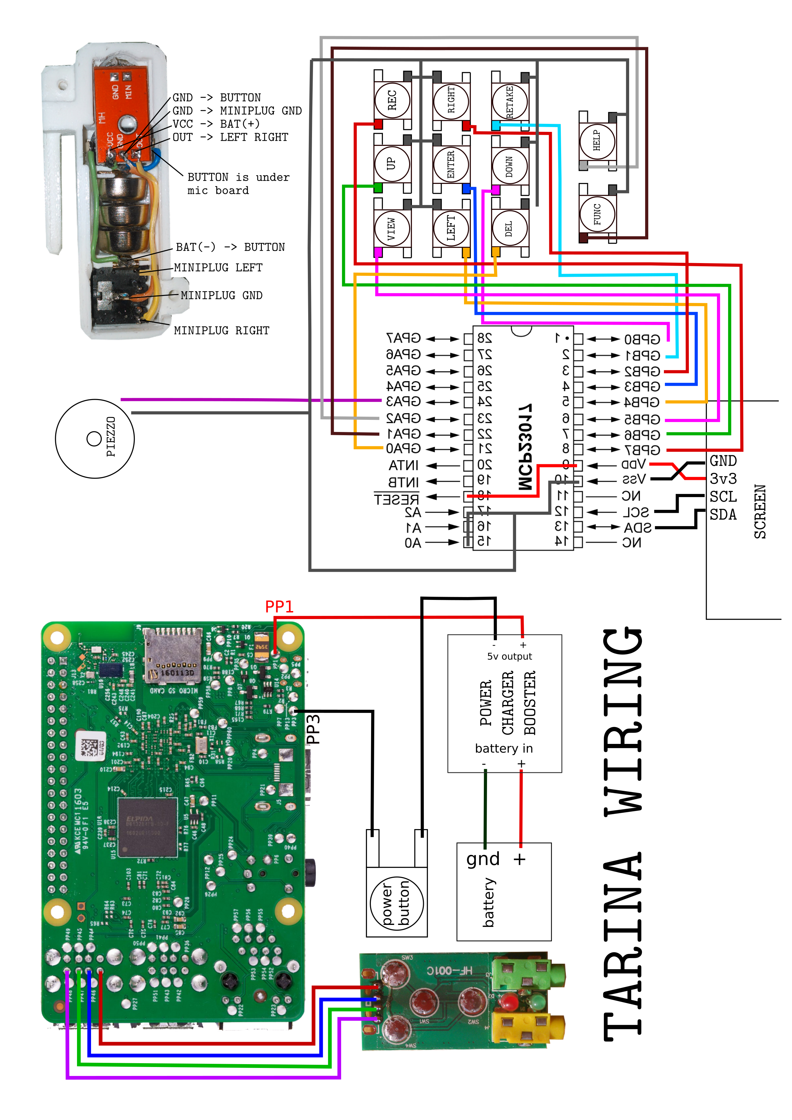
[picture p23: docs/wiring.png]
Tarina wiring diagram


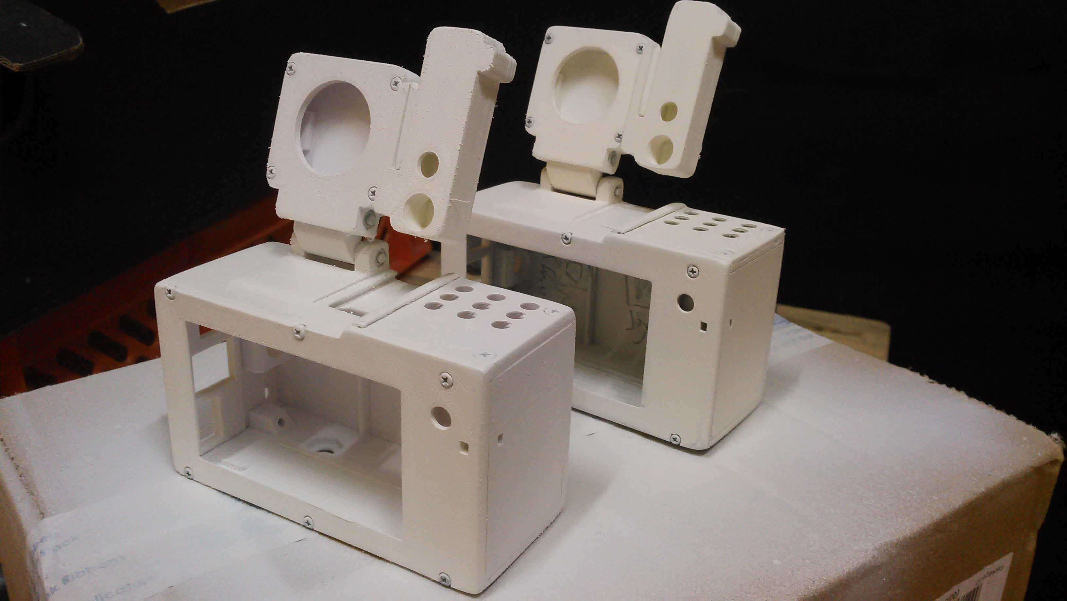
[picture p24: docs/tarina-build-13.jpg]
3d printed and painted, next up sanding and adding one more paint layer


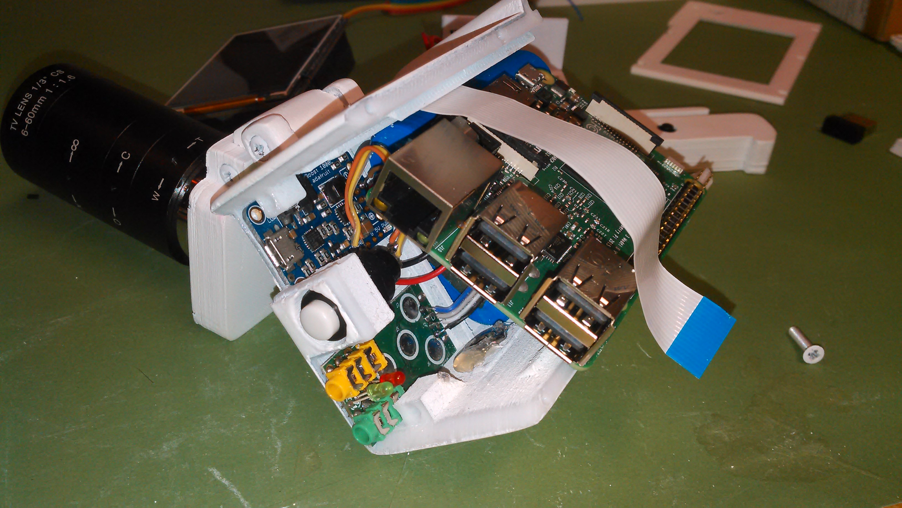
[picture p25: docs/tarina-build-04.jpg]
Fitting everything together


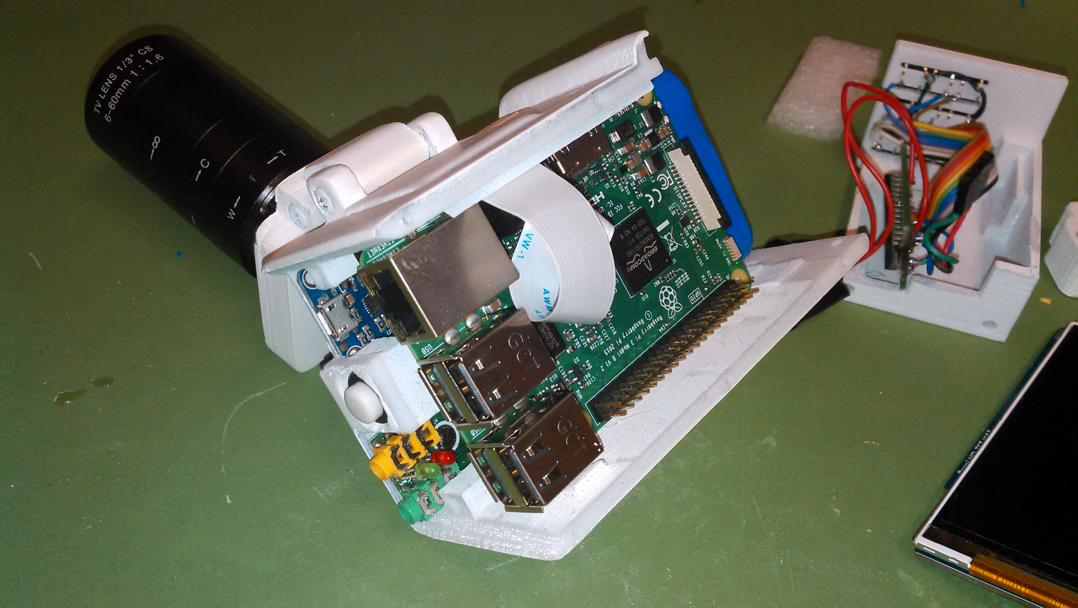
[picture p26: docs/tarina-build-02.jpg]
Ready for screen


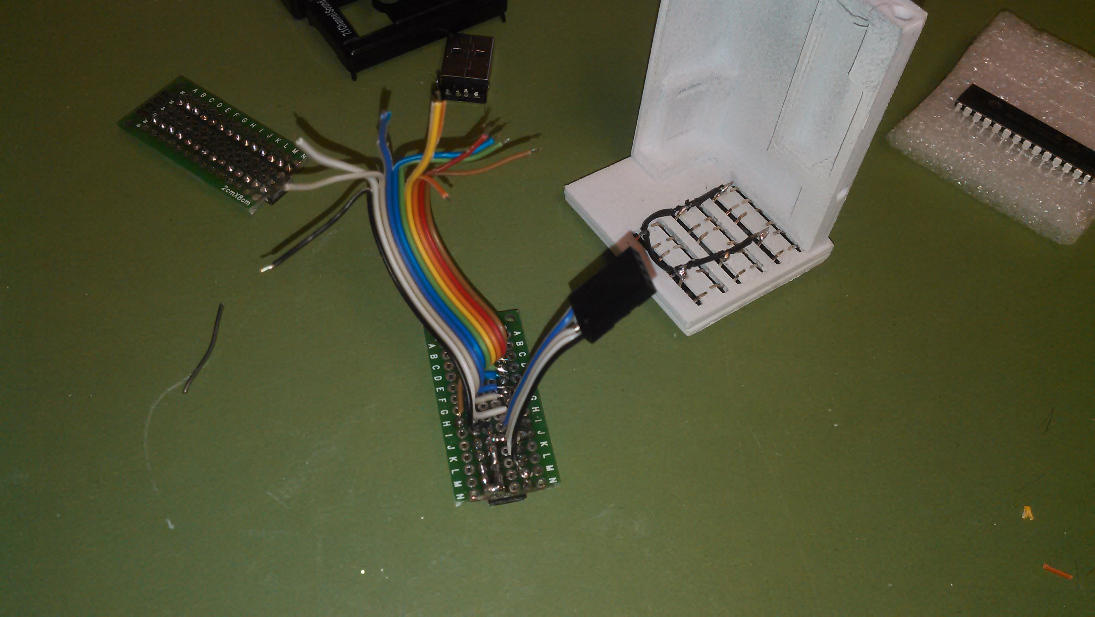
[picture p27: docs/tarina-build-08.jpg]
MCP and buttons


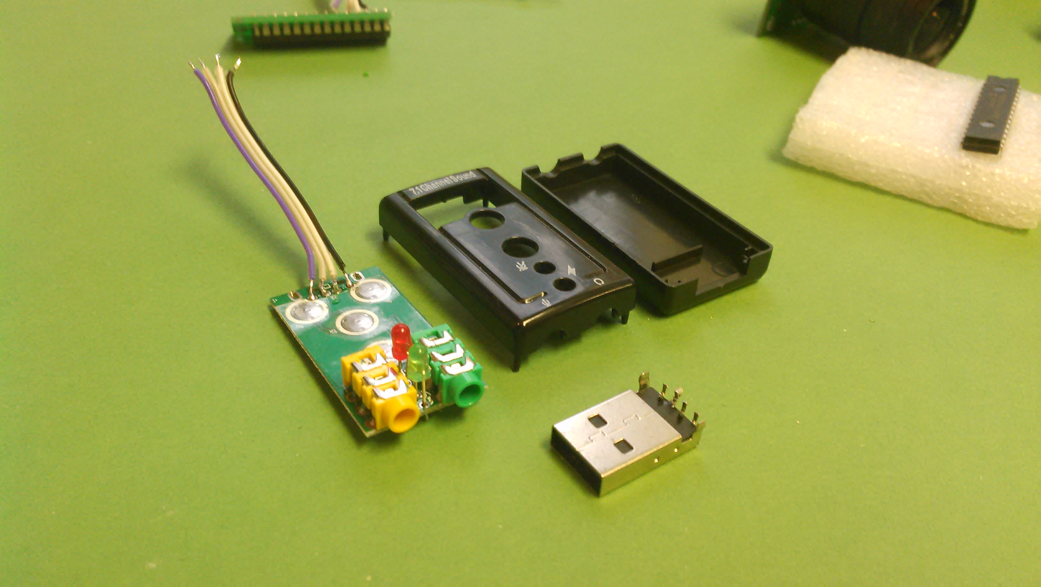
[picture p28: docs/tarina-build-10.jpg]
Sound card ready to be soldered


Putting it together
===================

Documentation on its way, if you're in a hurry feel free to drop a message in [#tarina:matrix.tarina.org](https://riot.im/app/#/room/#tarina:matrix.tarina.org)

Installing software
===================

Download latest [Raspbian](https://www.raspberrypi.org/downloads/raspbian/) and follow [install instructions](https://www.raspberrypi.org/documentation/installation/installing-images/README.md).
[Ssh into](https://www.raspberrypi.org/documentation/remote-access/ssh/) Raspberry Pi and run:

Go to home folder
```
cd /home/pi
```
Install git
```
sudo apt-get install git
```
Git clone tarina and then run install script with sudo:
```
git clone https://github.com/rbckman/tarina.git
cd tarina
sudo ./install.sh
```
You'r ready to rumble:
```
python3 tarina.py
```
Happy filming!

Should be looking like this once finnished

Tested lenses
=============

Here is what I'm testing right now.

2.8mm 3MP F1.2 CS
-----------------
Price ~ 6 €

This is a good wide all around lens. Recomended!
[Aliexpress](https://www.aliexpress.com/item/32973023765.html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,searchweb201602_7,searchweb201603_55)

2.5mm 3MP F1.2 CS
-----------------
Price ~ 6 €

This is an even wider lens. Seems to be the same manufacterer.
[Aliexpress](https://www.aliexpress.com/item/32970488708.html?spm=a2g0o.detail.1000023.1.782e6003A85K1u)

Yumiki 6-60mm 1/3" CS Lens CCTV Lens IR F1.6 Manual Zoom Manual Iris 
--------------------------------------------------------------------

[Aliexpress](https://www.aliexpress.com/item/6-60mm-1-3-CS-Lens-CCTV-Lens-IR-F1-6-Manual-Zoom-Manual-Iris-for/32793850795.html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)

Camera Lens 2.8-12mm Varifocal
------------------------------

This lens is good. Will write a longer review once I have more filming hours.

[Aliexpress](https://www.aliexpress.com/item/Megapixel-Fixed-Iris-HD-CCTV-Camera-Lens-2-8-12mm-Varifocal-HD-Security-Camera-Lens-Manual/32644427822.html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)

---

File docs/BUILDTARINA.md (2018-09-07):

<link rel="stylesheet" href="style.css" type="text/css" rel="stylesheet"/>

TARINA BUILD INSTRUCTIONS
=========================

Build instructions for the lazy filmmakers. If your dog dies while building this I am not responsible.

[Buy the parts](#buy-the-parts)

[3d printing](#3d-printing)

[Post processing](#post-processing)

[Soldering stuff](#soldering-stuff)

[Putting it together](#putting-it-together)

[Installing software](#installing-software)

[Tested lenses](#tested-lenses)

---

Tarina parts layed out

---

Buy the parts
=============

Here is a list of parts that will work, there are other parts that probably will work but this is what I recommend. 

---

Raspberry pi 3 B
----------------
Price ~30 eur

The heart of Tarina. Why Raspberry pi you ask? There are several reasons:

* Available everywhere.
* Huge support.
* The great Debian based os Raspbian (beeing a debian nerd myself).
* Low price.
* Picamera.

The 3B+ is too powerhungry for the Powerbooster 1000C thats why I went with 3B

**Links**
[Raspberry pi site](https://raspberrypi.org)
**Buy**
[Aliexpress](https://www.aliexpress.com/store/product/Raspberry-Pi-3-Model-B-Raspberry-Pi-Raspberry-Pi3-B-Pi-3-Pi-3B-With-WiFi/3242037_32900816535.html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,searchweb201602_5_10065_10068_5016020_5015416_10059_10696_100031_5015320_10084_10083_10103_451_10618_452_5016116_10304_10307_10820_10821_10302,searchweb201603_55,ppcSwitch_2&algo_expid=0a48bb10-5985-49ff-be76-433eb1f8685b-15&algo_pvid=0a48bb10-5985-49ff-be76-433eb1f8685b&priceBeautifyAB=0)

---

Arducam 8 MP Sony IMX219 camera module with CS lens 2718
--------------------------------------------------------
Price ~60 eur

This module and lens gives good hd video quality with the ability to manually focus and replace lenses. See tested lenses down below.

**Links**
[Arducam](http://arducam.com/)
**Buy**
[uctronics](http://www.uctronics.com/arducam-8-mp-sony-imx219-camera-module-with-cs-lens-2717-for-raspberry-pi.html)

---

Ugeek 3.5 inch 800x480 TFT Screen
---------------------------------
Price ~35 eur

Best 3.5 inch screen that I could find. Features worth mentioning:

* 800x480 pixels
* Very responsible 11 ms.
* High contrast.
* Sunlight readable.
* I2C Master.

This is not a touchscreen but I dont think touchscreens are good for cameras anyway. 

**Links**
[Raspberrypiwiki](http://www.raspberrypiwiki.com/index.php/3.5_inch_TFT_800x480@60fps)
**Buy**
[Aliexpress](https://www.aliexpress.com/store/product/U-Geek-Raspberry-Pi-3-5-inch-800-480-TFT-Screen-HD-HighSpeed-LCD-Module-3/1954241_32672157641.html)

---

USB via vt1620a Sound card
--------------------------
Price ~1 eur

Really cheap usb soundcard. It has been working suprisingly well. Have not tested other cards yet.

**Buy**
[Aliexpress](https://www.aliexpress.com/item/Professional-External-USB-Sound-Card-Adapter-Virtual-7-1-Channel-3D-Audio-with-3-5mm-Headset/32588038556.html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)

---

3.7v 7800mAh li-ion Battery
---------------------------
Price ~17 eur

I have tried several batteries, the adafruit 6800mAh is also fine.

**Buy**
[Aliexpress](https://www.aliexpress.com/item/free-shipping-3-7v-7800mah-18650-li-ion-rechargeable-battery-pack-18650-3P-lithium-ion-battery/32823635264.html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)

---

Adafruit Powerboost 1000C
-------------------------
Price ~23 eur

This is the only power board that I could find with the feature to run the camera and charge it at the same time.

**Links**
[Adafruit](https://www.adafruit.com/product/2465)
**Buy**
[Ebay](https://www.ebay.com/itm/Adafruit-PowerBoost-1000-Charger-Rechargeable-5V-Lipo-USB-Boost-1A-1000C-A/282083284436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)

---

8x8x5MM DIP-4 Silicone Switch Mute Silent button
------------------------------------------------
Price ~2 eur/20 pcs

You can only buy a pack of 20 pcs but these buttons are good and silent! Not necessary if you want to control with keyboard like Rii mini 8+

**Buy**
[Ebay](http://www.ebay.com/itm/151723036469?_trksid=p2057872.m2749.l2649&ssPageName=STRK%3AMEBIDX%3AIT)

---

MCP23017-E/SP DIP-28 16 Bit I / O Expander I2C
-----------------------------------------------
Price ~1 eur

This will be connected to the screen I2C port. This is not necessary if you intend to control the camera with a keyboard like the Rii mini i8+

**Buy**
[Aliexpress](https://www.aliexpress.com/item/10PCS-MCP23017-E-SP-DIP-28-MCP23017-16-Bit-I-O-Expander-with-I2C-Interface-IC/32665631086.html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)

---

Piezo Electronic Buzzer
-----------------------
Price ~1 eur

Very useful for timing shots!

**Buy**
[Aliexpress](https://www.aliexpress.com/store/product/New-Arrival-Durable-3-24V-Piezo-Electronic-Buzzer-Alarm-95DB-Continuous-Sound-Beeper-For-Arduino-Car/1959068_32666789405.htm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,searchweb201602_3_10065_10068_10059_5015413_5015313_10696_100031_10084_10083_5016113_10103_451_10618_452_10304_10307_10820_10821_10302_5016013,searchweb201603_45,ppcSwitch_4_ppcChannel&algo_expid=c84318cd-b50e-4370-9cad-6ae9bc7963ae-0&algo_pvid=c84318cd-b50e-4370-9cad-6ae9bc7963ae&priceBeautifyAB=0)

---

1A 30V DC 250V Black Latching On Off Mini Torch Push Button Switch
-------------------------------------------------------------------
Price ~1 eur/10 pcs

This serves as the microphone and screen on/off button

**Buy**
[Aliexpress](https://www.aliexpress.com/item/10Pcs-Set-1A-30V-DC-250V-Black-Latching-On-Off-Mini-Torch-Push-Button-Switch-G08/32756874522.html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)

---

Latching push button switch 10mm fixed
--------------------------------------
Price ~5 eur/24 pcs

I use this as the powerbutton. I have tried different versions of safe shutdown buttons for the Raspberry pi but they have not worked as I wanted (they draw power even when Pi is powered off, this is not good). I have solved the problem with a menu button to safely shut down the camera. 

**Buy**
[Aliexpress](https://www.aliexpress.com/item/24pcs-latching-push-button-switch-10mm-fixed-pushbutton-switch-latching-maintained-push-buttons/32770346793.html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)

---

Stainless Steel Hex Full Nut 1/4 inch -20 UNC 304 A2 
------------------------------------------------
Price ~2 eur/10 pcs

This is the standard camera stand nuts. If you never use a stand then you dont need this.

**Buy**
[Ebay](https://www.ebay.com/itm/1-4-20-UNC-304-A2-Stainless-Steel-Hex-Full-Nuts-Qty-10PCS-/222134363896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)<br>

---

MAX9812 Microphone Amplifier
----------------------------
Price ~2 eur

This makes suprisingly good sounding sound!

**Buy**
[Aliexpress](https://www.aliexpress.com/item/MIC-microphone-amplifier-module-sound-module-voice-module/32268198506.html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)

---

3.5mm Female 5 Pins Stereo Headset Interior PCB Mount Audio
-----------------------------------------------------------
Price ~1 eur/10 pcs

Microphone input.

**Buy**
[Ebay](https://www.ebay.com/itm/10pcs-3-5mm-Female-5-Pins-Stereo-Headset-Interior-PCB-Mount-Audio-Jack-Socket-/252376936189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)

---

LR44 Batteries
--------------
Price ~2 eur/10 pcs

Microphone batteries

**Buy**
[Aliexpress](https://www.aliexpress.com/store/product/10PCS-Lot-100-Genuine-wholesale-GP-A76-GPA76-LR44-AG13-LR44-SR44-battery-LR44-357-AG13/1120058_32739450265.html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,searchweb201602_5_10065_10068_5015418_5016020_10059_10696_100031_5015320_10084_10083_10103_451_10618_452_10304_10307_10820_10821_5016118_10302,searchweb201603_55,ppcSwitch_2&algo_expid=8af0bcbe-dcb8-4f9a-bd47-084a4d77561a-6&algo_pvid=8af0bcbe-dcb8-4f9a-bd47-084a4d77561a&priceBeautifyAB=0)

---

Screws M3x12
-----------
Price ~2 eur/25 pcs

These hold the camera together.

**Buy**
Your local harware store
[Motonet (store in Finland)](https://www.motonet.fi/fi/tuote/389247/Uraruuvi-3x12-A2-RST-25kpl)

---

Screws 2.2x9.5mm
----------------
Price ~1 eur/20 pcs

These hold the camera/mic together.

**Buy**
Your local hardware store
[Hobbycenter (store in Finland)](https://www.hobbycenter.fi/kavan-puuruuvi-22x95mm-20-kpl-0096a)

---

LR44 Button Cell Battery Socket Holder
--------------------------------------
Price ~1 eur/pcs

We only need the metal parts from these, if you have som thin metal you could cut these yourself.

**Buy**
[Aliexpress](https://www.aliexpress.com/item/5Pcs-lot-AG13-LR44-Button-Cell-Battery-Socket-Holder-Plastic-Case-TBH-AG13-B/32833837989.html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)

---

3.5mm Jack to Jack Aux Cable
----------------------------
Price ~1 eur

From microphone to mic-in.

**Buy**
[Aliexpress](https://www.aliexpress.com/store/product/1-Piece-Short-0-2M-20cm-Red-3-5mm-Jack-to-Jack-Aux-Cable-Male-to/505072_32833465555.html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,searchweb201602_5_10065_10068_5016020_10059_10696_100031_5015320_5016120_10084_10083_5015420_10103_451_10618_452_10304_10307_10820_10821_10302,searchweb201603_55,ppcSwitch_2&algo_expid=9ba0b376-e66f-48d2-9ccd-ecc1e8794812-1&algo_pvid=9ba0b376-e66f-48d2-9ccd-ecc1e8794812&priceBeautifyAB=0) 

---

Rii mini i8+ mini keyboard
--------------------------
Price ~17 eur

Wireless control over camera. You will also need this for wifi settings etc. (Recommended) This is one of the best mini keyboards I've tried. 

**Buy**
[Aliexpress](https://www.aliexpress.com/item/Rii-mini-i8-Russian-English-Spanish-Hebrew-Version-Wireless-Backlit-Keyboard-with-Touchpad-for-PC-Smart/32450468690.html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)

---

Parts grand total ~200 eur

---

3d printing
===========

While waiting for ordered parts lets 3d print the rest of the parts. I recommend printing with a solid 90% infill. Now it is pretty crucial that you have a good calibrated printer so that you don't over/under print. Some parts need to be very precise to work.

You'll find all the 3d parts in the 3d folder.

* [body](https://github.com/rbckman/tarina/blob/master/3d/tarina-body.stl)
* [button-plate-bottom](https://github.com/rbckman/tarina/blob/master/3d/tarina-button-plate-bottom.stl)
* [button-plate-upper](https://github.com/rbckman/tarina/blob/master/3d/tarina-button-plate-upper.stl)
* [hdmi-cap](https://github.com/rbckman/tarina/blob/master/3d/tarina-hdmi-cap.stl)
* [left-side](https://github.com/rbckman/tarina/blob/master/3d/tarina-left-side.stl)
* [mic-body](https://github.com/rbckman/tarina/blob/master/3d/tarina-mic-body.stl)
* [mic-lid](https://github.com/rbckman/tarina/blob/master/3d/tarina-mic-lid.stl)
* [picamera-body](https://github.com/rbckman/tarina/blob/master/3d/tarina-picamera-body.stl)
* [picamera-body-lid](https://github.com/rbckman/tarina/blob/master/3d/tarina-picamera-body-lid.stl)
* [picamera-bridge](https://github.com/rbckman/tarina/blob/master/3d/tarina-picamera-bridge.stl)
* [right-side](https://github.com/rbckman/tarina/blob/master/3d/tarina-right-side.stl)
* [screen-lid](https://github.com/rbckman/tarina/blob/master/3d/tarina-screen-lid.stl)

---

Post processing
===============

This is still a work in progress...

So far I've come to this conclusion:

* Sanded with multiple grit/sandpaper from rough to the finest (from 120 to 400)
* Paint first two layers
* Sand again
* Paint two layers again
* Continue til satisfied

---

Soldering stuff
===================

Documentation on its way, if your in a hurry feel free to drop a message in [telegram](https://t.me/tarinadiy)

---

Putting it together
===================

Documentation is on its way, if your in a hurry feel free to drop a message in [telegram](https://t.me/tarinadiy)

---

Installing software
===================

Download latest [Raspbian](https://www.raspberrypi.org/downloads/raspbian/) and follow [install instructions](https://www.raspberrypi.org/documentation/installation/installing-images/README.md).
[Ssh into](https://www.raspberrypi.org/documentation/remote-access/ssh/) Raspberry Pi and run:
```
sudo raspi-config
```
Expand file system, enable camera and then reboot.
Run this to install git:
```
sudo apt-get install git
```
Git clone tarina and then run install script with sudo:
```
git clone https://rbckman@bitbucket.org/rbckman/tarina.git
cd tarina
sudo ./install.sh
```
You'r ready to rumble:
```
python tarina.py
```
Happy filming!

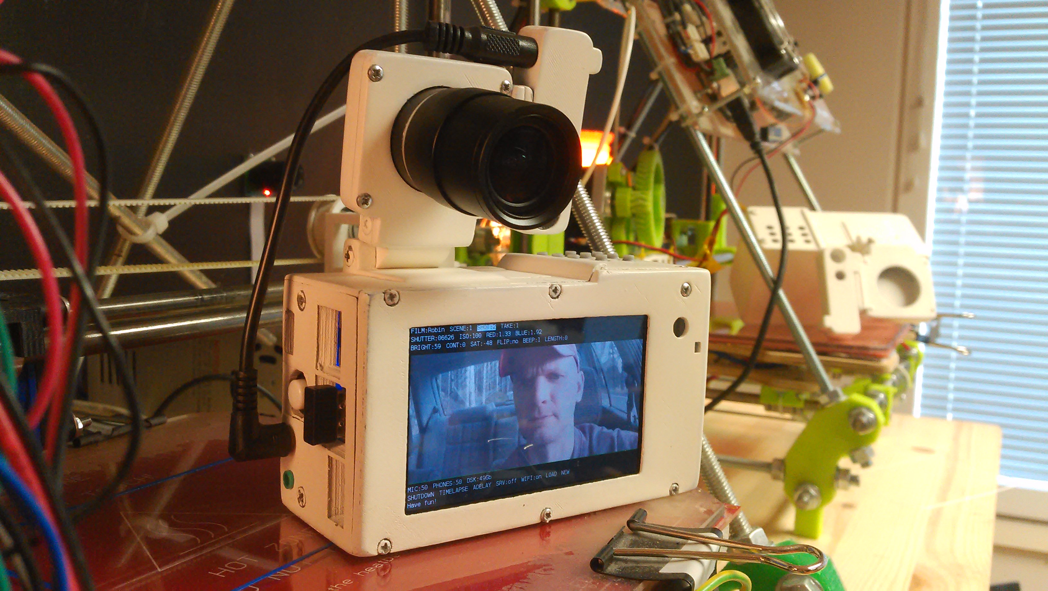
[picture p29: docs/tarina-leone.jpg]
Should be looking like this once finnished


---

Tested lenses
=============

Here is what I'm testing right now.

---

Yumiki 6-60mm 1/3" CS Lens CCTV Lens IR F1.6 Manual Zoom Manual Iris 
--------------------------------------------------------------------

[Aliexpress](https://www.aliexpress.com/item/6-60mm-1-3-CS-Lens-CCTV-Lens-IR-F1-6-Manual-Zoom-Manual-Iris-for/32793850795.html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)

---

Camera Lens 2.8-12mm Varifocal
------------------------------

This lens is good. Will write a longer review once I have more filming hours.

[Aliexpress](https://www.aliexpress.com/item/Megapixel-Fixed-Iris-HD-CCTV-Camera-Lens-2-8-12mm-Varifocal-HD-Security-Camera-Lens-Manual/32644427822.html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)

---

that's all folks...

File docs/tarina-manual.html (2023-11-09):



# MANUAL



Filming with Tarina

## Contents

### The interface

1. Introduction
2. Keys
3. Menus
4. Faq

### [Building, repairing & modding]

1. Get the parts
2. 3d printing
3. Post processing
4. Wiring
5. Putting it together
6. Installing software
7. Tested lenses

# Introduction



Tarina UI

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

## Retake function

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

# Keys

### Buttons



Buttons

### Keyboard



Buttons

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

Special keys on the keyboard (CAPITAL):

C = Copy scene/shot

M = Cut (as in cut and paste) scene/shot

I = Insert empty or copied scene/shot

space / pgup = Rec / Stop

pgdwn / backspace = Retake

tab = view

# Menus

A short explanation of all the settings and why they are where they are.

### Film, scene, shot and take

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

### Dubbing

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

### Shutter, iso, red, blue

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

### Bright, cont, sat

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

### Flip, beep, lenght

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

### Mic, phones, comp

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

### Timelapse

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

### Lens

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

### Dsk, shutdown, srv, wifi

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

### Update and upload

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

to get the youtube api secrets wget https://tarina.org/yt/.client_secrets.json

### Backup

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

### Load and new

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

# Building, repairing and modding

## Get the parts



Tarina parts layed out

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

## Raspberry pi 3 B

Price ~30 eur

The heart of Tarina. Why Raspberry pi you ask? There are several reasons:

- Huge support.
- The great Debian based os Raspbian (beeing a debian nerd myself).
- Low price.
- Picamera.

The 3B+ is too powerhungry for the Powerbooster 1000C thats why I went with 3B

Links Raspberry pi site (https://raspberrypi.org) Buy Aliexpress (https://www.aliexpress.com/store/product/Raspberry-Pi-3-Model-B-Raspberry-Pi-Raspberry-Pi3-B-Pi-3-Pi-3B-With-WiFi/3242037_32900816535.html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)

## 64 Gb Samsung Evo+ Micro SD

Price ~10 eur

This is a good performance card.

Aliexpress (https://www.aliexpress.com/item/32676225311.html)

## Raspberry Pi High Quality Camera (recommended)

Price ~60 eur

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

Links Buy Raspberry pi (https://www.raspberrypi.org/products/raspberry-pi-high-quality-camera/?resellerType=home)

## Arducam 5 MP OV5647 camera module with CS lens

Price ~30 eur

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

## Pimoroni Hyperpixel 4 inch screen

Price ~35 eur

Bright 4 inch responsible screen. Beware when installing the screen, it’s quite britle!

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

## Ugeek 3.5 inch 800x480 TFT screen

Price ~35 eur

Best 3.5 inch screen that I could find. Features worth mentioning:

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

This is not a touchscreen but I dont think touchscreens are good for cameras anyway.

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

## USB via vt1620a sound card

Price ~1 eur

Really cheap usb soundcard. It has been working suprisingly well. Have not tested other cards yet.

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

## 3.7v 7800mAh li-ion Battery

Price ~17 eur

I have tried several batteries, the adafruit 6800mAh is also fine.

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

Aliexpress (https://www.aliexpress.com/item/32826851071.html?spm=a2g0s.9042311.0.0.27424c4dUBojcv)

Here’s a pack with 40 pcs of 2600mAh 3.7V 18650 cells.

Aliexpress (https://www.aliexpress.com/item/32795814865.html?spm=a2g0s.9042311.0.0.27424c4dUBojcv)

## Type-C 5v 2A 3.7V Li-ion battery charger booster module

Price ~2€

Enough juice in this booster charger to run teh pi 3b without dropping voltage.

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

## Adafruit Powerboost 1000C

Price ~23 eur

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

Links Adafruit (https://www.adafruit.com/product/2465) Buy Ebay (https://www.ebay.com/itm/Adafruit-PowerBoost-1000-Charger-Rechargeable-5V-Lipo-USB-Boost-1A-1000C-A/282083284436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) Aliexpress (https://www.aliexpress.com/item/32881790567.html)

## 8x8x5MM DIP-4 Silicone Switch Mute Silent button

Price ~2 eur/20 pcs

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

## MCP23017-E/SP DIP-28 16 bit I / O expander I2C

Price ~1 eur

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

## 2x8cm double side copper prototype pcb

Price ~0.20 eur/pcs

PCB board to solder all connections on the MCP23017-E/SP

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

## Piezo electronic buzzer

Price ~1 eur

Very useful for timing shots!

Buy Aliexpress (https://www.aliexpress.com/store/product/New-Arrival-Durable-3-24V-Piezo-Electronic-Buzzer-Alarm-95DB-Continuous-Sound-Beeper-For-Arduino-Car/1959068_32666789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)

## Latching push button switch mini

Price ~1 eur/10 pcs

This serves as the microphone and screen on/off button

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

## Latching push button switch 10mm

Price ~5 eur/24 pcs

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

## Nut 1/4 -20 UNC 304 A2

Price ~2 eur/10 pcs

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

## MAX9812 Microphone amplifier

Price ~2 eur

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

Buy Aliexpress (https://www.aliexpress.com/item/32793366801.html) (out of stock) Ebay (https://www.ebay.com/itm/MAX9812-Microphone-Amplifier-Sound-MIC-Voice-Module-For-Arduino-3-3V-3-5V/123891576683) (out of stock)

New module (still untested) Aliexpress (https://www.aliexpress.com/item/33052676199.html) Bigger electrec mics (if needed) Aliexpress (https://www.aliexpress.com/item/32639718325.html?spm=a2g0s.9042311.0.0.27424c4d7cO7CI)

## 3.5mm Female stereo headset interior PCB mount

Price ~1 eur/10 pcs

Microphone input.

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

## LR44 Batteries

Price ~2 eur/10 pcs

Microphone batteries

Buy Aliexpress (https://www.aliexpress.com/store/product/10PCS-Lot-100-Genuine-wholesale-GP-A76-GPA76-LR44-AG13-LR44-SR44-battery-LR44-357-AG13/1120058_32739450265.html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)

## Screws M3x12mm

Price ~2 eur/25 pcs

These hold the camera together.

Buy Your local harware store

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

## Screws M3x30mm

Price ~2 eur/30 pcs

These hold picamera-body to the body.

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

## Screws 2.2x9.5mm

Price ~1 eur/20 pcs

These hold the camera/mic together.

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

## LR44 Button cell socket holder

Price ~1 eur/pcs

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

## 3.5mm Jack to jack aux cable

Price ~1 eur

From microphone to mic-in.

Buy Aliexpress (https://www.aliexpress.com/store/product/1-Piece-Short-0-2M-20cm-Red-3-5mm-Jack-to-Jack-Aux-Cable-Male-to/505072_32833465555.html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)

## Rii mini i8+ mini keyboard

Price ~17 eur

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

Parts grand total ~200 eur

# Optional parts

## Tarina viewfinder

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

## Lens D42 F110mm

Price ~10 eur

Buy Aliexpress (https://www.aliexpress.com/item/32958816619.html?spm=a2g0s.9042311.0.0.6fb54c4dGb4wI7)

## Rubber Eyepiece

Price ~4 eur

Buy Aliexpress (https://www.aliexpress.com/item/32780859922.html?spm=a2g0s.9042311.0.0.27424c4dmVqriG)

## Magnets 25mm x 5mm x 1.5mm

Price ~3 eur 10 pcs

Buy Aliexpress (https://www.aliexpress.com/item/32963277127.html?spm=a2g0s.9042311.0.0.27424c4dRc1vCZ)

# 3d printing

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

You’ll find all the 3d parts in the 3d folder.

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

# Post processing

This is still a work in progress…

So far I’ve come to this conclusion:

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

# Wiring



Tarina wiring diagram



3d printed and painted, next up sanding and adding one more paint layer



Fitting everything together



Ready for screen



MCP and buttons



Sound card ready to be soldered

# Putting it together

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

# Installing software

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

Go to home folder

cd /home/pi

Install git

sudo apt-get install git

Git clone tarina and then run install script with sudo:

git clone https://github.com/rbckman/tarina.git
cd tarina
sudo ./install.sh

You’r ready to rumble:

python3 tarina.py

Happy filming!



Should be looking like this once finnished

# Tested lenses

Here is what I’m testing right now.

## 2.8mm 3MP F1.2 CS

Price ~ 6 €

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

## 2.5mm 3MP F1.2 CS

Price ~ 6 €

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

## Yumiki 6-60mm 1/3" CS Lens CCTV Lens IR F1.6 Manual Zoom Manual Iris

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

## Camera Lens 2.8-12mm Varifocal

This lens is good. Will write a longer review once I have more filming hours.

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

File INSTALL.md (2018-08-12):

## Tarina install instructions ##

Run the automatic install script with sudo:
```
sudo ./install.sh
```
you are done! now reboot & Tarina will start at bootup:
```
sudo reboot
```

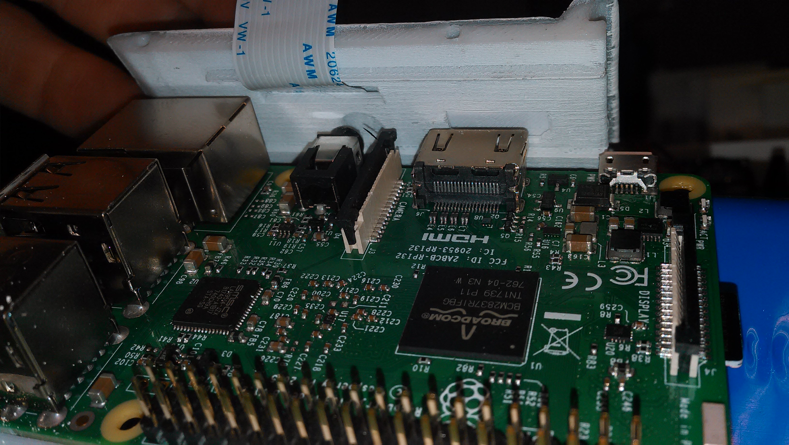
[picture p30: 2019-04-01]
docs/tarina-build-03.jpg

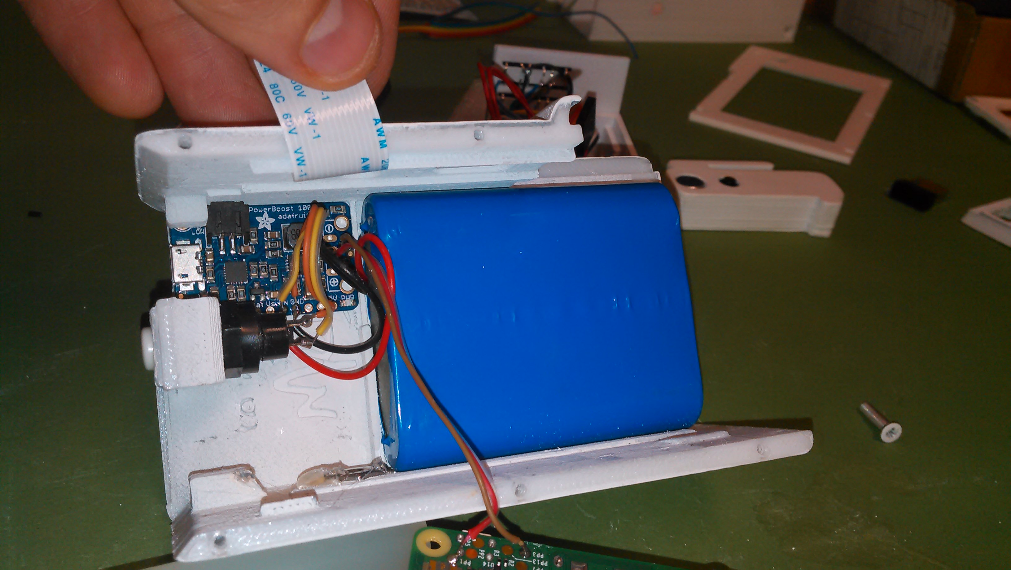
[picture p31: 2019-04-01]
docs/tarina-build-05.jpg

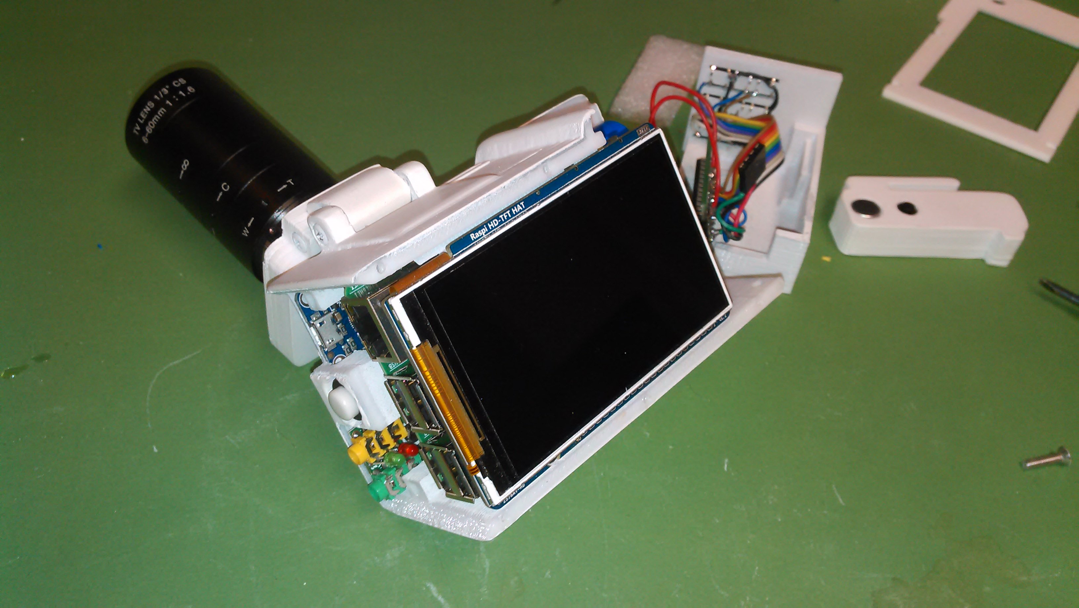
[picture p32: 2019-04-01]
docs/tarina-build-01.jpg

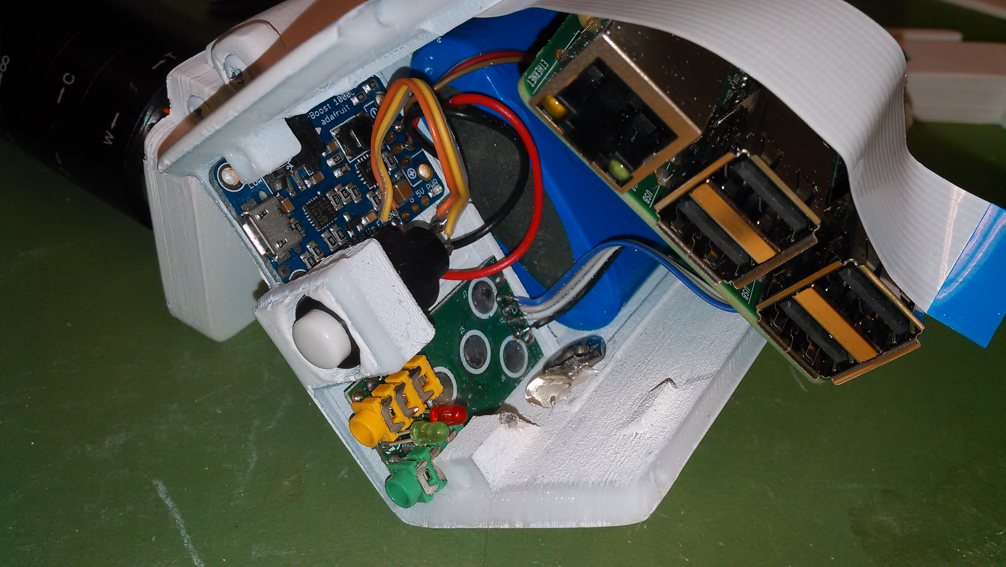
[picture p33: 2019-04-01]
docs/tarina-build-07.jpg

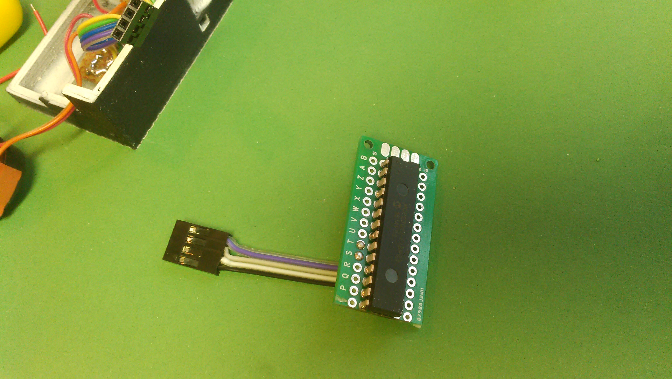
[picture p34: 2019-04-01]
docs/tarina-build-11.jpg

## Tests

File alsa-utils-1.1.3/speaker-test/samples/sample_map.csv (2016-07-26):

0 | "Front Left" | "/usr/share/alsa/samples/Front_Left.wav"
1 | "Front Right" | "/usr/share/alsa/samples/Front_Right.wav"

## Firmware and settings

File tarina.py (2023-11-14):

#!/usr/bin/env python3
# -*- coding: utf-8 -*-


#   ````````  ``````  ```````  ```  ```` ```  ``````  
#   `  ``` `  `` ```  ```  ``` ```  ````  ``  `` ```  
#      ```   ```````  ``` ```` ```  ````````  ``````  
#      ```   ``   ``  ``````   ```  `` ````` ```  ``  
#      ```  ```   ``` ```  ``` ``` ```  ```` ```  ``` 
#     ````   ``` ```` ```  ``` ``` ````  ``` ```  ````

# a Muse of Filmmaking
# https://tarina.org

import picamerax as picamera
import numpy as np
import string
import os
import time
import datetime
import multiprocessing as mp
from subprocess import call
from subprocess import Popen
from omxplayer import OMXPlayer
from multiprocessing import Process, Queue
import subprocess
import sys
import pickle
import RPi.GPIO as GPIO
from PIL import Image
import socket
import configparser
import shortuuid
import smbus
import ifaddr
import web

#import shlex
from blessed import Terminal

# bless the code!
term = Terminal()

#DEBIAN VERSION
pipe = subprocess.check_output('lsb_release -c -s', shell=True)
debianversion = pipe.decode().strip()
print('running debian ' + debianversion)

#I2CBUTTONS
probei2c = 0
while probei2c < 3:
    try:
        if debianversion == "stretch":
            os.system('sudo modprobe i2c-dev')
            bus = smbus.SMBus(3) # Rev 2 Pi uses 1
        else:
            os.system('sudo modprobe i2c-dev')
            bus = smbus.SMBus(11) # Rev 2 Pi uses 1
        DEVICE = 0x20 # Device address (A0-A2)
        IODIRB = 0x0d # Pin pullups B-side
        IODIRA = 0x00 # Pin pullups A-side 0x0c
        IODIRApullup = 0x0c # Pin pullups A-side 0x0c
        GPIOB  = 0x13 # Register B-side for inputs
        GPIOA  = 0x12 # Register A-side for inputs
        OLATA  = 0x14 # Register for outputs
        bus.write_byte_data(DEVICE,IODIRB,0xFF) # set all gpiob to input
        bus.write_byte_data(DEVICE,IODIRApullup,0xF3) # set two pullup inputs and two outputs 
        bus.write_byte_data(DEVICE,IODIRA,0xF3) # set two inputs and two outputs 
        bus.write_byte_data(DEVICE,OLATA,0x4)
        print("yes, found em i2c buttons!")
        i2cbuttons = True
        break
    except:
        print("could not find i2c buttons!! running in keyboard only mode")
        print("trying again...")
        i2cbuttons = False
        probei2c += 1
        time.sleep(1)
        bus=''

#MAIN
def main():
    global headphoneslevel, miclevel, tarinafolder, screen, loadfilmsettings, plughw, channels, filmfolder, scene, showmenu, rendermenu, quality, profilelevel, i2cbuttons, menudone, soundrate, soundformat, process, serverstate, que, port, recording, onlysound, camera_model, fps_selection, fps_selected, fps, db, selected, cammode, newfilmname, camera_recording, abc
    # Get path of the current dir, then use it as working directory:
    rundir = os.path.dirname(__file__)
    if rundir != '':
        os.chdir(rundir)
    #filmfolder = "/home/pi/Videos/"
    #picfolder = "/home/pi/Pictures/"
    tarinafolder = os.getcwd()

    #MENUS
    standardmenu = 'FILM:', 'SCENE:', 'SHOT:', 'TAKE:', '', 'SHUTTER:', 'ISO:', 'RED:', 'BLUE:', 'FPS:', 'Q:', 'BRIGHT:', 'CONT:', 'SAT:', 'FLIP:', 'BEEP:', 'LENGTH:', 'HW:', 'CH:', 'MIC:', 'PHONES:', 'COMP:', 'TIMELAPSE', 'MODE:', 'DSK:', 'SHUTDOWN', 'SRV:', 'SEARCH:', 'WIFI:', 'UPDATE', 'UPLOAD', 'BACKUP', 'LOAD', 'NEW', 'TITLE', 'LIVE:'
    tarinactrlmenu = 'FILM:', 'SCENE:', 'SHOT:', 'TAKE:', '', 'SHUTTER:', 'ISO:', 'RED:', 'BLUE:', 'FPS:', 'Q:', 'BRIGHT:', 'CONT:', 'SAT:', 'FLIP:', 'BEEP:', 'LENGTH:', 'HW:', 'CH:', 'MIC:', 'PHONES:', 'COMP:', 'TIMELAPSE', 'MODE:', 'DSK:', 'SHUTDOWN', 'SRV:', 'SEARCH:', 'WIFI:', 'CAMERA:', 'Add CAMERA', 'New FILM', 'New SCENE', 'Sync SCENE'
    #tarinactrlmenu = "BACK","CAMERA:", "Add CAMERA","New FILM","","New SCENE","Sync SCENE","Snapshot"
    emptymenu='','','','','','','','','','','','','','','','','','','','','','','','','','','','','','','','','','','','','','','','','','','','','','','',''
    menu = standardmenu
    showtarinactrl = False
    recordwithports = False
    pressagain = ''
    #STANDARD VALUES (some of these may not be needed, should do some clean up)
    abc = '_','a','b','c','d','e','f','g','h','i','j','k','l','m','n','o','p','q','r','s','t','u','v','w','x','y','z','A','B','C','D','E','F','G','H','I','J','K','L','M','N','O','P','Q','R','S','T','U','V','W','X','Y','Z','1','2','3','4','5','6','7','8','9','0'
    numbers_only = ' ','1','2','3','4','5','6','7','8','9','0'
    keydelay = 0.0555
    selectedaction = 0
    selected = 0
    awb = 'auto', 'sunlight', 'cloudy', 'shade', 'tungsten', 'fluorescent', 'incandescent', 'flash', 'horizon'
    awbx = 0
    awb_lock = 'no'
    cammode = 'film'
    camera_model=''
    fps = 25
    fps_selected=2
    quality = 27
    profilelevel='4.2'
    headphoneslevel = 40
    miclevel = 50
    soundformat = 'S16_LE'
    soundrate = '48000'
    recording = False
    retake = False
    lastmenu = ''
    menudone = ''
    rendermenu = True
    showmenu = 1
    showmenu_settings = True
    showhelp = False
    overlay = None
    underlay = None
    reclenght = 0
    t = 0
    rectime = ''
    scene = 1
    shot = 1
    take = 1
    pic = 1
    onlysound=False
    filmname = 'onthefloor'
    newfilmname = ''
    beeps = 0
    beepcountdown = 0
    beeping = False
    backlight = True
    lastbeep = time.time()
    flip = 'no'
    between = 30
    duration = 0.2
    lenses = os.listdir('lenses/')
    lens = lenses[0]
    buttontime = time.time()
    pressed = ''
    buttonpressed = False
    holdbutton = ''
    updatethumb = False
    loadfilmsettings = True
    oldsettings = ''
    comp = 0
    yanked = ''
    copying = ''
    moving = False
    stream = ''
    live = 'no'
    peakshot = ''
    peaktake = ''
    plughw = 0 #default audio device
    channels = 1 #default mono
    #SAVE SETTINGS FREQUENCY IN SECS
    pausetime = time.time()
    savesettingsevery = 5
    #TARINA VERSION
    f = open(tarinafolder + '/VERSION')
    tarinaversion = f.readline()
    tarinavername = f.readline()

    #START INTERFACE
    startinterface()

    db=''
    #FIRE UP CAMERA
    camera = startcamera(lens,fps)
    #GET FILMFOLDER AND CAMERA VERSION
    camera_model, camera_revision , filmfolder = getconfig(camera)
    if os.path.isdir(filmfolder) == False:
        os.makedirs(filmfolder)

    #SYSTEM CONFIGS (turn off hdmi)
    #run_command('tvservice -o')
    #Kernel page cache optimization for sd card
    run_command('sudo ' + tarinafolder + '/extras/sdcardhack.sh')
    #Make screen shut off work and run full brightness
    run_command('gpio -g mode 19 pwm ')
    run_command('gpio -g pwm 19 1023')
    #COUNT DISKSPACE
    disk = os.statvfs(filmfolder)
    diskleft = str(int(disk.f_bavail * disk.f_frsize / 1024 / 1024 / 1024)) + 'Gb'

    #LOAD FILM AND SCENE SETTINGS
    try:
        filmname = getfilms(filmfolder)[0][0]
    except:
        filmname = filmname 
    try:
        filmname_back = getfilms(filmfolder)[0][1]
    except:
        filmname_back = filmname 

    #THUMBNAILCHECKER
    oldscene = scene
    oldshot = shot
    oldtake = take
    #TURN ON WIFI AND TARINA SERVER
    serverstate = 'on'
    wifistate = 'on'
    #serverstate = tarinaserver(False)
    #TO_BE_OR_NOT_TO_BE 
    foldername = filmfolder + filmname + '/' + 'scene' + str(scene).zfill(3) +'/shot' + str(shot).zfill(3) + '/'
    filename = 'take' + str(take).zfill(3)
    recordable = not os.path.isfile(foldername + filename + '.mp4') and not os.path.isfile(foldername + filename + '.h264')
    onthefloor_folder=filmfolder+'onthefloor'
    if os.path.isdir(onthefloor_folder) == False:
        os.makedirs(onthefloor_folder)

    #--------------Tarina Controller over socket ports --------#

    #TARINACTRL
    camerasconnected=''
    sleep=0.2
    cameras = []
    camerasoff =[]
    camselected=0
    newselected=0 
    mastersound=None
    camera_recording=None
    pingip=0
    searchforcameras='off'
    #NETWORKS
    networks=[]
    adapters = ifaddr.get_adapters()
    for adapter in adapters:
        print("IPs of network adapter " + adapter.nice_name)
        for ip in adapter.ips:
            if ':' not in ip.ip[0] and '127.0.0.1' != ip.ip:
                print(ip.ip)
                networks=[ip.ip]
    if networks != []:
        network=networks[0]
        if network not in cameras:
            cameras=[]
            cameras.append(network)

    port = 55555
    que = Queue()
    process = Process(target=listenforclients, args=("0.0.0.0", port, que))
    process.start()
    nextstatus = ''

    serverstate_old='off'
    wifistate_old='off'

    camera_model, camera_revision, filmfolder= getconfig(camera)

    #--------------MAIN LOOP---------------#
    while True:
        pressed, buttonpressed, buttontime, holdbutton, event, keydelay = getbutton(pressed, buttonpressed, buttontime, holdbutton)
        if pressagain != '':
            pressed = pressagain
            pressagain = ''
        #event = screen.getch()
        if wifistate != wifistate_old:
            if wifistate == 'on':
                run_command('sudo iwconfig wlan0 txpower auto')
            elif wifistate == 'off':
                run_command('sudo iwconfig wlan0 txpower off')
            wifistate_old = wifistate
        if serverstate != serverstate_old:
            if serverstate == 'on':
                tarinaserver(True)
            elif serverstate == 'off':
                tarinaserver(False)
            serverstate_old=serverstate
        if recording == False:
            #SHUTDOWN
            if pressed == 'middle' and menu[selected] == 'SHUTDOWN':
                writemessage('Hold on shutting down...')
                time.sleep(1)
                run_command('sudo shutdown -h now')
            #MODE
            elif pressed == 'changemode':
                if cammode == 'film':
                    cammode = 'picture'
                    vumetermessage('changing to picture mode')
                elif cammode == 'picture':
                    cammode = 'film'
                    vumetermessage('changing to film mode')
                camera.stop_preview()
                camera.close()
                camera = startcamera(lens,fps)
                loadfilmsettings = True
            #PICTURE
            elif pressed == 'picture':
                if os.path.isdir(foldername) == False:
                    os.makedirs(foldername)
                picture = foldername +'picture' + str(take).zfill(3) + '.jpeg'
                run_command('touch ' + foldername + '.placeholder')
                print('taking picture')
                camera.capture(picture,format="jpeg",use_video_port=True) 
            #PEAKING
            elif pressed == 'peak' and recordable == True:
                if shot > 1:
                    peakshot = shot - 1
                    peaktake = counttakes(filmname, filmfolder, scene, peakshot)
                p_imagename = filmfolder + filmname + '/scene' + str(scene).zfill(3) + '/shot' + str(peakshot).zfill(3) + '/take' + str(peaktake).zfill(3) + '.jpeg'
                overlay = displayimage(camera, p_imagename, overlay, 3)
                while holdbutton == 'peak':
                    pressed, buttonpressed, buttontime, holdbutton, event, keydelay = getbutton(pressed, buttonpressed, buttontime, holdbutton)
                    vumetermessage('peaking ' + str(peakshot))
                    time.sleep(0.03)
                overlay = removeimage(camera, overlay)
            #SHOWHELP
            elif pressed == 'showhelp':
                vumetermessage('Button layout')
                if showhelp == False:
                    overlay = removeimage(camera, overlay)
                    overlay = displayimage(camera, tarinafolder+'/extras/buttons.png', overlay, 4)
                    showhelp = True
                elif showhelp == True:
                    overlay = removeimage(camera, overlay)
                    updatethumb =  True
                    showhelp = False
                #while holdbutton == 'showhelp' or pressed == 'H':
                #    pressed, buttonpressed, buttontime, holdbutton, event, keydelay = getbutton(pressed, buttonpressed, buttontime, holdbutton)
                #    vumetermessage('Button layout')
                #    time.sleep(0.03)
            #TIMELAPSE
            elif pressed == 'middle' and menu[selected] == 'TIMELAPSE':
                overlay = removeimage(camera, overlay)
                takes = counttakes(filmname, filmfolder, scene, shot)
                if takes > 0:
                    shot = countshots(filmname, filmfolder, scene) + 1
                    take = 1
                foldername = filmfolder + filmname + '/' + 'scene' + str(scene).zfill(3) +'/shot' + str(shot).zfill(3) + '/'
                filename = 'take' + str(take).zfill(3)
                renderedfilename, between, duration = timelapse(beeps,camera,filmname,foldername,filename,between,duration,backlight)
                if renderedfilename != '':
                    #render thumbnail
                    #writemessage('creating thumbnail')
                    #run_command('avconv -i ' + foldername + filename  + '.mp4 -frames 1 -vf scale=800:460 ' + foldername + filename + '.jpeg')
                    updatethumb =  True
            #VIEW SCENE
            elif pressed == 'view' and menu[selected] == 'SCENE:':
                writemessage('Loading scene...')
                organize(filmfolder, filmname)
                filmfiles = shotfiles(filmfolder, filmname, scene)
                if len(filmfiles) > 0:
                    #Check if rendered video exist
                    camera.stop_preview()
                    #renderfilename, newaudiomix = renderscene(filmfolder, filmname, scene)
                    renderfilename = renderfilm(filmfolder, filmname, comp, scene, True)
                    if renderfilename != '':
                        remove_shots = playdub(filmname,renderfilename, 'film')
                        if remove_shots != []:
                            for i in remove_shots:
                                remove(filmfolder, filmname, scene, i, take, 'shot')
                            organize(filmfolder, filmname)
                            updatethumb = True
                            #loadfilmsettings = True
                            time.sleep(0.5)
                        else:
                            print('nothing to remove')
                        camera.start_preview()
                else:
                    vumetermessage("There's absolutely nothing in this scene! hit rec!")
                rendermenu = True
            #VIEW FILM
            elif pressed == 'view' and menu[selected] == 'FILM:':
                writemessage('Loading film...')
                organize(filmfolder, filmname)
                filmfiles = viewfilm(filmfolder, filmname)
                if len(filmfiles) > 0:
                    camera.stop_preview()
                    #removeimage(camera, overlay)
                    renderfilename = renderfilm(filmfolder, filmname, comp, 0, True)
                    if renderfilename != '':
                        remove_shots = playdub(filmname,renderfilename, 'film')
                    #overlay = displayimage(camera, imagename, overlay, 3)
                    camera.start_preview()
                else:
                    vumetermessage('wow, shoot first! there is zero, nada, zip footage to watch now... just hit rec!')
                rendermenu = True
            #VIEW SHOT OR TAKE
            elif pressed == 'view':
                writemessage('Loading clip...')
                organize(filmfolder, filmname)
                takes = counttakes(filmname, filmfolder, scene, shot)
                if takes > 0:
                    removeimage(camera, overlay)
                    camera.stop_preview()
                    foldername = filmfolder + filmname + '/scene' + str(scene).zfill(3) +'/shot' + str(shot).zfill(3) + '/'
                    filename = 'take' + str(take).zfill(3)
                    #compileshot(foldername + filename,filmfolder,filmname)
                    renderfilename, newaudiomix = rendershot(filmfolder, filmname, foldername+filename, scene, shot)
                    trim = playdub(filmname,foldername + filename, 'shot')
                    if trim:
                        take = counttakes(filmname, filmfolder, scene, shot)+1
                        trim_filename = foldername + 'take' + str(take).zfill(3)
                        videotrim(foldername + filename, trim_filename, trim[0], trim[1])
                        if os.path.exists(foldername+'dub') == True:
                            print('trim dubs here')
                    imagename = foldername + filename + '.jpeg'
                    overlay = displayimage(camera, imagename, overlay, 3)
                    camera.start_preview()
                else:
                    vumetermessage('nothing here! hit rec!')
                rendermenu = True
            #DUB SHOT
            elif pressed == 'middle' and menu[selected] == 'SHOT:' and recordable == False:
                newdub = clipsettings(filmfolder, filmname, scene, shot, take, plughw)
                take = counttakes(filmname, filmfolder, scene, shot)
                if newdub:
                    camera.stop_preview()
                    #save original sound
                    dubfolder = filmfolder + filmname + '/scene' + str(scene).zfill(3) + '/shot' + str(shot).zfill(3) + '/dub/'
                    saveoriginal = filmfolder + filmname + '/scene' + str(scene).zfill(3) + '/shot' + str(shot).zfill(3) + '/take'+str(take).zfill(3)+'.wav'
                    dubfiles, dubmix, newmix = getdubs(filmfolder, filmname, scene, shot)
                    foldername = filmfolder + filmname + '/scene' + str(scene).zfill(3) +'/shot' + str(shot).zfill(3) + '/'
                    filename = 'take' + str(take).zfill(3)
                    if dubfiles==[]:
                        print('no dubs, copying original sound to original')
                        os.system('cp '+saveoriginal+' '+dubfolder+'original.wav')
                        time.sleep(2)
                    renderfilename, newaudiomix = rendershot(filmfolder, filmname, foldername+filename, scene, shot)
                    playdub(filmname,renderfilename, 'dub')
                    #run_command('sox -V0 -G /dev/shm/dub.wav -c 2 ' + newdub)
                    #add audio/video start delay sync
                    run_command('sox -V0 -G /dev/shm/dub.wav -c 2 /dev/shm/temp.wav trim 0.013')
                    run_command('mv /dev/shm/temp.wav '+ newdub)
                    audiosync, videolenght, audiolenght = audiotrim(renderfilename, 'end', newdub)
                    vumetermessage('new shot dubbing made!')
                    camera.start_preview()
                    time.sleep(1)
                else:
                    vumetermessage('see ya around!')
                rendermenu = True
            #DUB SCENE
            elif pressed == 'middle' and menu[selected] == 'SCENE:':
                newdub = clipsettings(filmfolder, filmname, scene, 0, take, plughw)
                if newdub:
                    camera.stop_preview()
                    renderfilename, newaudiomix = renderscene(filmfolder, filmname, scene)
                    playdub(filmname,renderfilename, 'dub')
                    #run_command('sox -V0 -G /dev/shm/dub.wav -c 2 ' + newdub)
                    #add audio/video start delay sync
                    run_command('sox -V0 -G /dev/shm/dub.wav -c 2 /dev/shm/temp.wav trim 0.013')
                    run_command('mv /dev/shm/temp.wav '+ newdub)
                    audiosync, videolenght, audiolenght = audiotrim(renderfilename, 'end', newdub)
                    vumetermessage('new scene dubbing made!')
                    camera.start_preview()
                    time.sleep(1)
                else:
                    vumetermessage('see ya around!')
                rendermenu = True
            #DUB FILM
            elif pressed == 'middle' and menu[selected] == 'FILM:':
                newdub = clipsettings(filmfolder, filmname, 0, 0, take, plughw)
                if newdub:
                    camera.stop_preview()
                    renderfilename = renderfilm(filmfolder, filmname, comp, 0, False)
                    playdub(filmname,renderfilename, 'dub')
                    run_command('sox -V0 -G /dev/shm/dub.wav -c 2 ' + newdub)
                    vumetermessage('new film dubbing made!')
                    camera.start_preview()
                    time.sleep(1)
                else:
                    vumetermessage('see ya around!')
                rendermenu = True
            #BACKUP
            elif pressed == 'middle' and menu[selected] == 'BACKUP':
                copytousb(filmfolder)
                rendermenu = True
            #UPLOAD
            elif pressed == 'middle' and menu[selected] == 'UPLOAD':
                if webz_on() == True:
                    filmfiles = viewfilm(filmfolder, filmname)
                    if len(filmfiles) > 0:
                        renderfilename = renderfilm(filmfolder, filmname, comp, 0, True)
                        cmd = uploadfilm(renderfilename, filmname)
                        if cmd != None:
                            stopinterface(camera)
                            try:
                                run_command(cmd)
                            except:
                                logger.warning('uploadfilm bugging')
                            startinterface()
                            camera = startcamera(lens,fps)
                            loadfilmsettings = True
                        selectedaction = 0
                rendermenu = True
            #LOAD FILM
            elif pressed == 'middle' and menu[selected] == 'LOAD':
                filmname = loadfilm(filmname, filmfolder)
                loadfilmsettings = True
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

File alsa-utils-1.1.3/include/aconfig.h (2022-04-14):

/* include/aconfig.h.  Generated from aconfig.h.in by configure.  */
/* include/aconfig.h.in.  Generated from configure.ac by autoheader.  */

/* directory containing alsa configuration */
#define DATADIR "/usr/share/alsa"

/* Define to 1 if translation of program messages to the user's native
   language is requested. */
#define ENABLE_NLS 1

/* Define if curses-based programs can show translated messages. */
#define ENABLE_NLS_IN_CURSES 1

/* Define to 1 if you have the <alsa/mixer.h> header file. */
#define HAVE_ALSA_MIXER_H 1

/* Define to 1 if you have the <alsa/pcm.h> header file. */
#define HAVE_ALSA_PCM_H 1

/* Define to 1 if you have the <alsa/rawmidi.h> header file. */
#define HAVE_ALSA_RAWMIDI_H 1

/* Define to 1 if you have the <alsa/seq.h> header file. */
#define HAVE_ALSA_SEQ_H 1

/* Define to 1 if you have the <alsa/topology.h> header file. */
#define HAVE_ALSA_TOPOLOGY_H 1

/* Define to 1 if you have the <alsa/use-case.h> header file. */
#define HAVE_ALSA_USE_CASE_H 1

/* Define to 1 if you have the MacOS X function CFLocaleCopyCurrent in the
   CoreFoundation framework. */
/* #undef HAVE_CFLOCALECOPYCURRENT */

/* Define to 1 if you have the MacOS X function CFPreferencesCopyAppValue in
   the CoreFoundation framework. */
/* #undef HAVE_CFPREFERENCESCOPYAPPVALUE */

/* Have clock gettime */
#define HAVE_CLOCK_GETTIME 1

/* Have curses set_escdelay */
#define HAVE_CURSES_ESCDELAY 1

/* Define if the GNU dcgettext() function is already present or preinstalled.
   */
#define HAVE_DCGETTEXT 1

/* Define to 1 if you have the <form.h> header file. */
#define HAVE_FORM_H 1

/* Define if the GNU gettext() function is already present or preinstalled. */
#define HAVE_GETTEXT 1

/* Define if you have the iconv() function and it works. */
/* #undef HAVE_ICONV */

/* Define to 1 if you have the <inttypes.h> header file. */
#define HAVE_INTTYPES_H 1

/* Define to 1 if you have the `asound' library (-lasound). */
#define HAVE_LIBASOUND 1

/* Define to 1 if you have the `fftw3f' library (-lfftw3f). */
/* #undef HAVE_LIBFFTW3F */

/* Define to 1 if you have the `m' library (-lm). */
#define HAVE_LIBM 1

/* Define to 1 if you have the `pthread' library (-lpthread). */
#define HAVE_LIBPTHREAD 1

/* Have librt */
#define HAVE_LIBRT 1

/* Define to 1 if you have the `tinyalsa' library (-ltinyalsa). */
/* #undef HAVE_LIBTINYALSA */

/* Define to 1 if you have the <memory.h> header file. */
#define HAVE_MEMORY_H 1

/* Define to 1 if you have the <menu.h> header file. */
#define HAVE_MENU_H 1

/* Define to 1 if you have the <panel.h> header file. */
#define HAVE_PANEL_H 1

/* Define to 1 if you have the <samplerate.h> header file. */
/* #undef HAVE_SAMPLERATE_H */

/* alsa-lib supports snd_seq_client_info_get_card */
#define HAVE_SEQ_CLIENT_INFO_GET_CARD 1

/* alsa-lib supports snd_seq_client_info_get_pid */
#define HAVE_SEQ_CLIENT_INFO_GET_PID 1

/* Define to 1 if you have the <stdint.h> header file. */
#define HAVE_STDINT_H 1

/* Define to 1 if you have the <stdlib.h> header file. */
#define HAVE_STDLIB_H 1

/* Define to 1 if you have the <strings.h> header file. */
#define HAVE_STRINGS_H 1

/* Define to 1 if you have the <string.h> header file. */
#define HAVE_STRING_H 1

/* Define to 1 if you have the <sys/stat.h> header file. */
#define HAVE_SYS_STAT_H 1

/* Define to 1 if you have the <sys/types.h> header file. */
#define HAVE_SYS_TYPES_H 1

/* Define to 1 if you have the <unistd.h> header file. */
#define HAVE_UNISTD_H 1

/* Name of package */
#define PACKAGE "alsa-utils"

/* Define to the address where bug reports for this package should be sent. */
#define PACKAGE_BUGREPORT ""

/* Define to the full name of this package. */
#define PACKAGE_NAME "alsa-utils"

/* Define to the full name and version of this package. */
#define PACKAGE_STRING "alsa-utils 1.1.3"

/* Define to the one symbol short name of this package. */
#define PACKAGE_TARNAME "alsa-utils"

/* Define to the home page for this package. */
#define PACKAGE_URL ""

/* Define to the version of this package. */
#define PACKAGE_VERSION "1.1.3"

/* directory containing sample data */
#define SOUNDSDIR "/usr/share/sounds/alsa"

/* Define to 1 if you have the ANSI C header files. */
#define STDC_HEADERS 1

/* Define to 1 if you can safely include both <sys/time.h> and <time.h>. */
#define TIME_WITH_SYS_TIME 1

/* ALSA util version */
#define VERSION "1.1.3"

/* Enable large inode numbers on Mac OS X 10.5.  */
#ifndef _DARWIN_USE_64_BIT_INODE
# define _DARWIN_USE_64_BIT_INODE 1
#endif

/* Number of bits in a file offset, on hosts where this is settable. */
#define _FILE_OFFSET_BITS 64

/* Define for large files, on AIX-style hosts. */
/* #undef _LARGE_FILES */

/* Define to empty if `const' does not conform to ANSI C. */
/* #undef const */

/* Define to `__inline__' or `__inline' if that's what the C compiler
   calls it, or to nothing if 'inline' is not supported under any name.  */
#ifndef __cplusplus
/* #undef inline */
#endif

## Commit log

2016-07-26 All files
    [PetPiCam-raspb2-m12lens-body.stl, PetPiCam-raspb2-m12lens-bodyrightside.stl, PetPiCam-raspb2-m12lens-bridge.stl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]
2016-07-26 error if no internet connection while updating
    [tarina.py]
2016-07-27 Check if button pressed and write menu file
2016-07-27 Bug fixes and remove function
    [main.c, tarina.py]
2016-07-28 Bug fixes and write menu only when needed
    [main.c, tarina.py]
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2016-11-02 proto3, 3d files
    [PetPiCam-raspb2-m12lens-body.stl, PetPiCam-raspb2-m12lens-bodyrightside.stl, PetPiCam-raspb2-m12lens-bridge.stl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]
2016-11-02 added bridge
    [tarina-proto3.stl]
2016-11-02 tarina proto5
    [tarina-proto3.stl]
2016-11-02 oldpirates ye de rabbai
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2017-02-19 fixed mic volume and vu meter
    [main.c, tarina.py]
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2017-03-06 tarina model 2017
    [tarina-2017-buttonholder.stl, tarina-2017-buttonholderlid.stl, tarina-2017-leftside.stl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]
2017-03-06 button delay fix
2017-03-09 shutdown button fix
2017-03-12 button bug fixed and set minimum film lenght
    [tarina.py]
2017-11-24 audio is now always longer than video, no more cracks in the edit
    [tarina.py]
2018-07-05 3d model update
    [tarina-2017-buttonholder.stl, tarina-2017-buttonholderlid.stl, tarina-2017-leftside.stl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]
2018-07-13 3d model, more space for button soldering
2018-08-09 remove atx power module, added support for adafruit powerboost 1000c
2018-08-09 make second last frame thumbnail
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2018-08-13 clips organizes correctly when removed, thumbnail code much cleaner
    [tarina.py]
2018-08-16 install script fixed, dropped frames fixes
    [tarina.py]
2018-08-17 new 3d files
    [tarina-body.stl, tarina-button-plate-bottom.stl, tarina-button-plate-upper.stl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]
2018-08-17 many fixes! start and stop interface is now cleaner, u can now jump in to wicd-curses from interface
    [tarina.py]
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2018-08-19 remove film added, keyboard shortcuts improved, name film improved
    [tarina.py]
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2018-08-26 trying openflexure lens shading table, also fixed omxplayer bug
    [tarina.py]
2018-08-28 bug fix & lens shade testing
    [tarina.py]
2018-08-29 Turn off pi leds and hdmi, set priority to nicer in systemd unit file, recompiled alsa-utils
2018-08-29 remove old files
    [tarina-body&support.stl, tarina-bridge.stl, tarina-buttonplate-down.stl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]
2018-08-29 lens shading correction for cs lens, thanks to rwb27!
2018-08-29 added install dependencies for rwb27s fork of picamera with added lens shading correction
2018-08-31 mic holder update
    [tarina-body.stl, tarina-button-screen-lid.stl, tarina-left-side.stl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]
2018-09-06 microphone clip should now be more stiff
    [tarina-body.stl, tarina-mic-body.stl, tarina-mic-lid.stl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]
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2018-09-14 body works with 12 mm srews now
    [tarina-body.stl, tarina-button-plate-bottom.stl, tarina-button-plate-upper.stl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]
2018-09-16 new lens config, check if file excist before playing it
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2018-10-29 buzz added when stop recording
    [tarina.py]
2018-11-07 mic lid fix
    [tarina-body.stl, tarina-button-plate-bottom.stl, tarina-button-plate-upper.stl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]
2018-11-15 reverted back to picamera v1 due to lens shading issues with v2 and cs lens
    [tarina.py]
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2018-11-15 picamera change to v1 due to better lens shading correction
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2019-04-19 bug fix when removing a take, should now work. show films in order last modified on browser. basic implementation of dubbing feature
    [tarina.py]
2019-04-19 timelapse audio silence fixed
    [tarina.py]
2019-04-19 timelapse audio bug fixed
    [tarina.py]
2019-04-25 pump up to new alsa-tools-1.1.3, maybe zombie bug fixed?!
    [sample_map.csv]
2019-04-25 png freezr bug fixed https://github.com/waveform80/picamera/issues/62
    [tarina.py]
2019-04-25 comp missing in view scene
    [tarina.py]
2019-04-29 omxplayer wrapper dbus not connecting fixed
    [tarina.py]
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2019-04-29 fixing duration if video is longer
    [tarina.py]
2019-05-01 maybe omxplayer cannot connect to dbus fixed
    [tarina.py]
2019-05-06 wiring corrected
2019-05-08 more framerate fixes
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2019-05-15 quality to 23 due to dropping frames, timelapse minimum dur to 0.2 due to bad clips, added beeps to timelapse
2019-05-17 fix count last scene while copying removing scenes
    [tarina.py]
2019-05-31 trying modding kernel page caching to get it stop dropping frames also new film fix
    [tarina.py]
2019-05-31 dont update firmware! breaks camera module for some reason
2019-06-03 not so fast, reverting back to working.. need to do a different branch
    [tarina.py]
2019-06-05 blessed added, wiring fixed
2019-06-11 still copy/move not working
    [tarina.py]
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2019-06-26 bug settings was not loaded
    [tarina.py]
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2019-09-05 viewfinder model added
    [tarina-viewfinder.blend, tarina-viewfinder.stl]
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2019-09-05 the sweet spot between quality and usability in the encoder
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2019-09-10 picamera holder sturdier
    [tarina-body.stl, tarina-mic-body.stl, tarina-picamera-body.stl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]
2019-09-13 easy fit
    [tarina-mic-body.stl]
2019-09-14 broke scene renderer, this is why I should develop on another branch
    [tarina.py]
2019-09-14 remove audio track from mp4 file before adding new
2019-09-23 framerate change for rev.D and audiosync message longer
2019-10-07 still got dropped frames, reducing bitrate even further
2019-10-07 reduce quality more, we never want dropped frames anymore
2019-10-27 short video clips will now play! Yeas!
    [tarina.py]
2019-11-08 fixes on picamera walls and mic walls
    [tarina-body.stl, tarina-mic-body.stl, tarina-mic-lid.stl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]
2019-11-11 screen button height
    [tarina-body.stl, tarina-mic-body.stl, tarina-mic-lid.stl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]
2019-11-12 small fix to screen side button hole
    [tarina-body.stl, tarina-mic-body.stl, tarina-mic-lid.stl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]
2019-12-02 right side button fix
    [tarina-body.stl, tarina-mic-body.stl, tarina-mic-lid.stl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]
2019-12-02 insert scene now works, update thumbnail when removing a shot, space is _ in a filmname
2019-12-30 clean up blender file
    [tarina-body.stl, tarina-button-plate-bottom.stl, tarina-button-plate-upper.stl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]
2020-01-06 magnet cut outs a little bigger
    [tarina-viewfinder.blend, tarina-viewfinder.stl]
2020-01-19 youtube uploader now works correctly
    [tarina.py]
2020-02-02 repair all stls
    [tarina-body.stl, tarina-button-plate-bottom.stl, tarina-button-plate-upper.stl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]
2020-02-17 fix scene render names
    [tarina.py]
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2020-03-09 change the default sound module, usb audio device change in buster
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2020-11-13 using picamerax, fixing some install dependencies
    [tarina.py]
2020-11-27 new i2c func button added, now new i2c button keys; insert, copy move and peak. also changed keyboard shortcuts for copy and move
    [tarina.py]
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2021-01-20 change module secrets to shortuuid
    [tarina.py]
2021-01-20 probe i2c again if fail
    [tarina.py]
2021-03-01 new picamera hq body
    [tarina-body.stl, tarina-button-plate-bottom.stl, tarina-button-plate-upper.stl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]
2021-03-04 still fixing the settings
    [tarina.py]
2021-03-22 dont throw error if not playing while pause
    [tarina.py]
2021-03-29 fast forward or reverse video with up and down keys
    [tarina.py]
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2021-04-07 two buttons added, make room for hyperpixel screen
    [tarina-body.stl, tarina-button-plate-bottom.stl, tarina-button-plate-upper.stl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]
2021-04-07 recalculate outside
    [tarina-body.stl]
2021-04-08 3d model repair
    [tarina-right-side.stl, tarina-screen-lid-hyperpixel.stl]
2021-04-11 buttons added, wiring corrected
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2021-04-11 flip mcp2317, better for soldering
2021-04-12 added screen glas
    [tarina-body.stl, tarina-button-plate-bottom.stl, tarina-button-plate-upper.stl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]
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2021-04-14 body fix
    [tarina-body.stl]
2021-04-30 default values to brightness, contrast and saturation on middle button press
2021-07-06 if stream fails, notice about it and continue
    [tarina.py]
2021-07-13 added dub help line, fixed some kahfuao
    [tarina.py]
2022-01-01 fix render bug when only one shot in a scene
    [tarina.py]
2022-01-01 dont error if no fastedit
    [tarina.py]
2022-01-18 cap for rainy days
    [tarina-body.stl, tarina-left-side-cap.stl, tarina-left-side.stl]
2022-04-14 binned 2028x1080 as standard mode for video, hide/show menu, shut screen power on off
2022-04-14 fix screwhandle, gonzo 180 angle and mic extension
    [tarina-body.stl, tarina-button-plate-bottom.stl, tarina-button-plate-upper.stl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]
2022-04-15 small fixes to 3d models
    [tarina-body.stl, tarina-picamera-screwhandle.stl]
2022-05-17 random freeze bug when hit back in omxplayer
    [tarina.py]
2022-11-07 3d files update
    [tarina-body.stl, tarina-button-plate-bottom.stl, tarina-button-plate-upper.stl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]
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2022-12-15 3d file update left side and body battery holder
    [tarina-body.stl, tarina-left-side.stl]
2023-01-10 fix stl, pics
    [tarina-body.stl, tarina-left-side-cap.stl, tarina-left-side.stl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]
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2023-01-25 no i2cbuttons but a yes to a screen
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2023-03-18 fps for imx477 audio correction
    [tarina.py]
2023-03-20 too much features soo many bugs to be fixed. but maybe now
    [tarina.py]
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2023-03-21 more strenght to body
    [tarina-body.stl]
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2023-03-23 viewfinder for hyperpixel screen
    [tarina-screen-lid-hyperpixel.stl, tarina-viewfinder-hyperpixel.stl]
2023-05-04 config broke, now fixed
    [tarina.py]
2023-05-05 usb soundcard wrong wiring, now fixed!
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2023-05-17 bug fix in organizer, use replace instead of strip, duuuuh!
    [tarina.py]
2023-07-06 viewfinder strap on
    [button-symbols.stl, tarina-body.stl, tarina-button-plate-bottom.stl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]
2023-07-07 strong camera character
    [tarina-body.stl, tarina-picamera-hq-body.stl, tarina-picamera-screwhandle.stl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]
2023-07-12 strooong camera character
    [tarina-body.stl, tarina-hdmi-cap.stl, tarina-left-side-cap.stl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]
2023-08-19 Revert "make ln!"
    This reverts commit 4e1a5c09ca3b23b05597bd520092ea9bd637c033.
    [tarina.py]
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2023-09-01 version Dandy Dandellion
    [tarina-body.stl, tarina-button-plate-bottom.stl, tarina-button-plate-upper.stl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]
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2023-09-11 cleanup 3d files
    [tarina-mic-body.stl, tarina-mic-lid.stl]
2023-09-21 sturdy mini plugs and all buttons
    [cs-extension-tube.stl, tarina-body.stl, tarina-button-plate-bottom.stl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]
2023-09-21 wiring fixed
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2023-11-07 func button moves
    [tarina-button-plate-bottom.stl, tarina-button-plate-upper.stl]
2023-11-07 some goodies, tarina loop for the tarina centidede
    [miniplug-bend-stopper.stl, tarinaloop.stl]
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2023-11-10 beeping from soundcard, also fixed a bug that sliped in while rewriting some of the rendershot, everything should work fine now!
    [tarina.py]
2023-11-10 bug in loadconfig, works now
    [tarina.py]
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2023-11-10 fix problems with render stops, should work now
    [tarina.py]
2023-11-11 wiring wrong!
    [tarina-picamera-clipgrip.stl]
